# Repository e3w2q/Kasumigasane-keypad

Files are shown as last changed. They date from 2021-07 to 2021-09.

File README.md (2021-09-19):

# Kasumigasane (霞襲)




## What is Kasumigasane?

Kasumigasane is a simple 16-key keypad that can be assembled without diodes.

*Kasumigasane* (霞襲) means "a layer of misty stuff", because it is made of layers of glass exposi substrates.

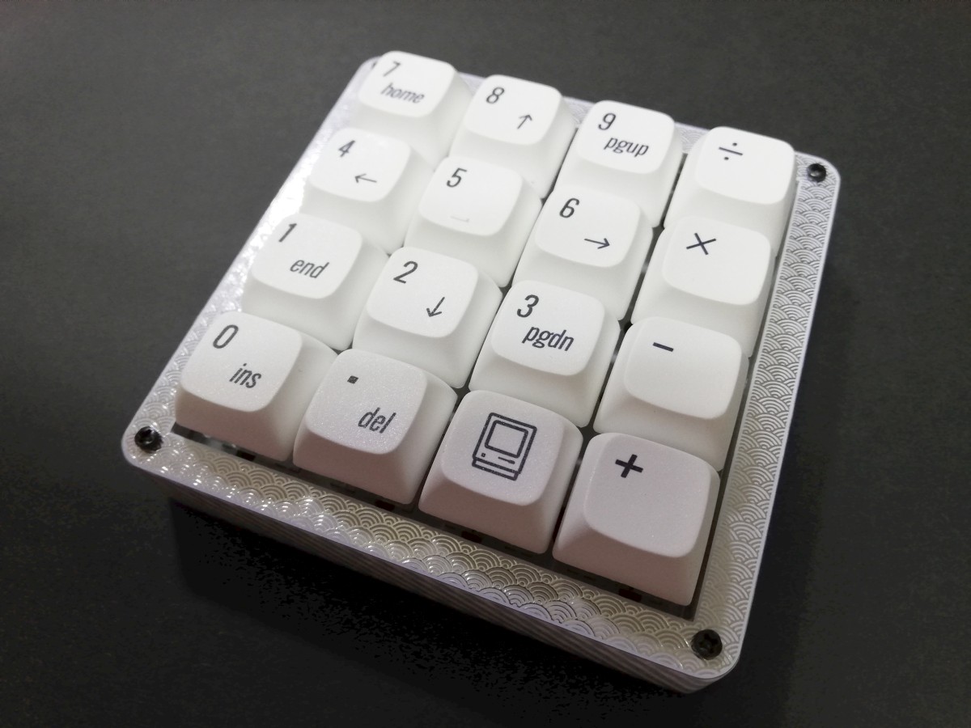
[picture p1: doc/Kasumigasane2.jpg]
Kasumigasane2


## Customizability

You can choose a frame from eight different patterns.

You can decorate the sides with 15mm wide masking tape.

The rightmost column and the lowermost row can use the 2U key.

The upper leftmost key can be replaced by a rotary encoder.

Backlight LED can be soldered.

## Link

[Hardware data (PCB)](pcb/)

[Firmware](https://github.com/e3w2q/qmk_firmware/tree/e3w2q/keyboards/e3w2q/kasumigasane)

[PCBの入手方法](doc/pcb_order_guide_jp.md)

[パーツリスト](doc/bom_list_jp.md)

[ビルドガイド](doc/readme_jp.md)

## Short Story

キーの上に指を走らせる。画面に文字が浮かび上がり、文章が出力されていく。つくづく現代、キータイプという作業と仕事は切り離せない関係になった。私のような文筆業のものにとっては、尚更である。<br />
キーボードは、ハードウェアと人間を繋ぐインターフェースのなかでもかなり原始的な部類のものだ。起源としては一八七三年に登場したタイプライターだが、日本語のワード・プロセッサーが登場したのは比較的最近の一九七九年。それでもおおよそ五〇年間、人間はこのデバイスと付き合ってきたと言っていい。<br />
その中でキーボードは進化を遂げてきた。キーボードは極論、『打った内容を正確にハードウェアに伝える』——ただそのためだけの役割の道具だが、人間の手に最も長い時間触れるデバイスの一つである。<br />
数々の高級キーボードが、進化の中で姿を現した。人間工学に配慮したもの、あるいは打鍵感を追求したもの、外見の高級感を備えたもの——近年では、自分に合うものをこそ自作しよう、という風潮まである。キーボードは簡単な電子回路と物理的接点、即ちスイッチがあれば実装できるデバイスでもある為だ。<br />
キリのいいところまで原稿を進めて、左手を横にスライドさせる。<br />
私は、目を走らせることなく、メインキーボードの横にあるキーを叩いた。——見ずとも打てるほどに慣れた配置。<br />
そう。メインキーボードの横には、四×四のオーソリニア・レイアウトをしたテンキーが鎮座している。これもまた、件の自作キーボードの一つだ。ベースは黒の落ち着いた筐体。好みでキートップはチェッカーフラッグ様の配色としてある。<br />
キー押下一つで、マクロが走り、エディタの校閲機能が起動、文章を精査する。——これも自作キーボードの魅力の一つだ。ユーザーがマクロ機能を作り込むことで、この小さなテンキーは作業効率を大きく変えうるワイルドカードとなる。<br />
あぶり出された誤字と誤用を、テンキー操作でジャンプしながら修正していく。<br />
明日も、明後日も、この小さな相棒は、私の手の左で、辣腕の執事のように活躍の機会を待っていてくれるだろう。<br />
——このテンキーの名前は、霞襲（かすみがさね）。

## Photos

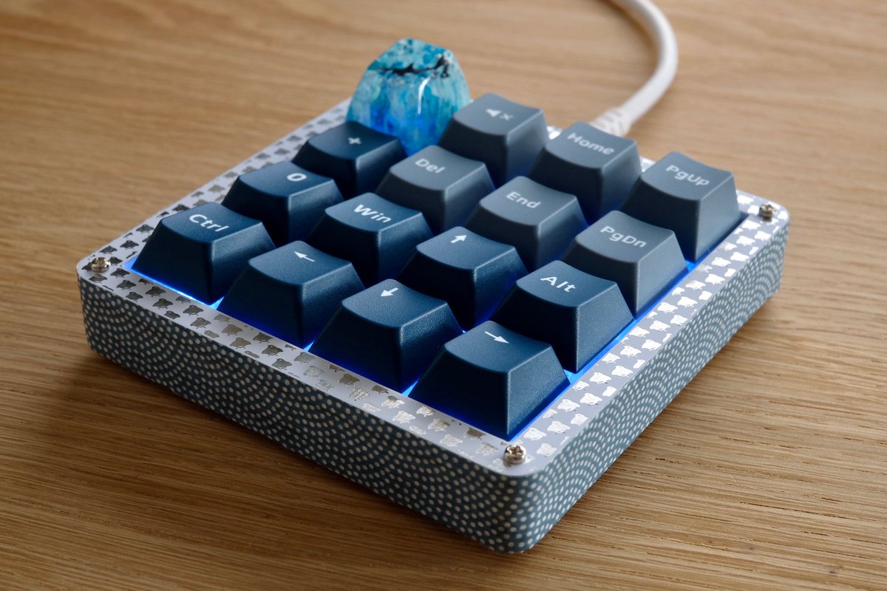
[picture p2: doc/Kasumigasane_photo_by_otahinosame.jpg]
Kasumigasane_photo_by_otahinosame


<small>Photo by @otahinosame</small>

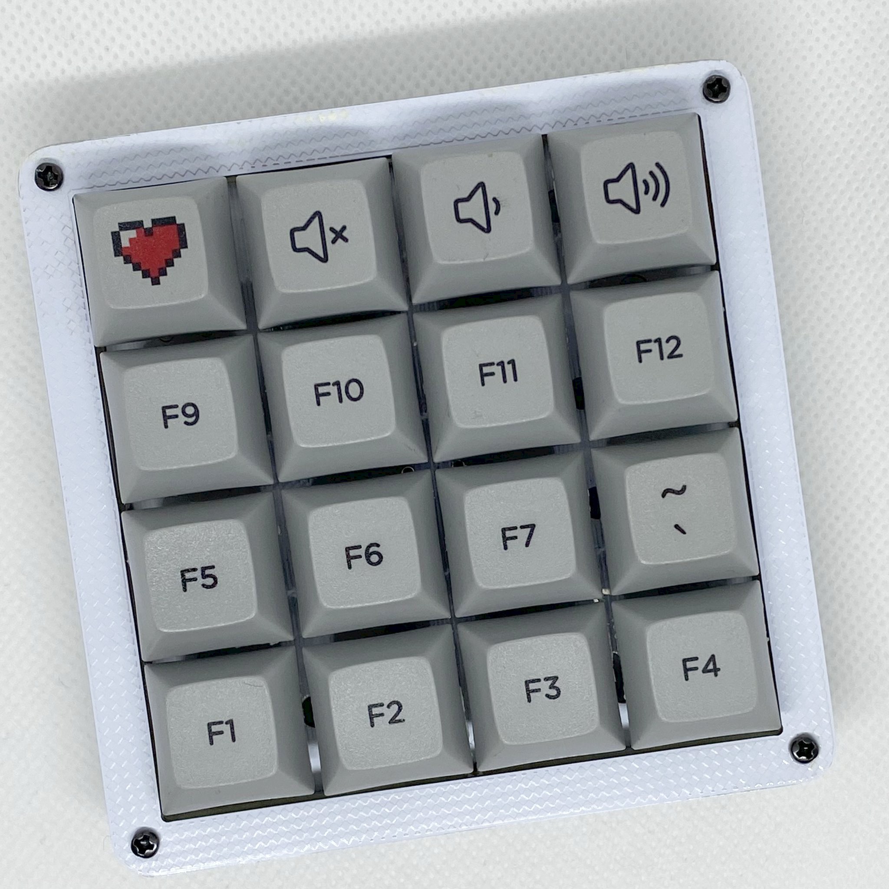
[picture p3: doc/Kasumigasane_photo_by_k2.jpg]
Kasumigasane_photo_by_k2


<small>Photo by @k2\_\_\_\_\_\_\_\_\_\_\_</small>

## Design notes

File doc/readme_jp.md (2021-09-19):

# 霞襲 ビルドガイド

<!-- TOC -->

- [霞襲 ビルドガイド](#霞襲-ビルドガイド)
    - [必要なパーツ](#必要なパーツ)
    - [使用する道具、消耗品](#使用する道具消耗品)
    - [組み方の選択](#組み方の選択)
    - [ビルドガイド](#ビルドガイド)
        - [Pro Microのもげ防止加工](#pro-microのもげ防止加工)
        - [基板のカット](#基板のカット)
        - [基板側面のヤスリがけ](#基板側面のヤスリがけ)
        - [はんだ付けのイメージトレーニング](#はんだ付けのイメージトレーニング)
        - [土台の組み立て](#土台の組み立て)
        - [Pro Microの取り付け](#pro-microの取り付け)
        - [ダイオードの取り付け](#ダイオードの取り付け)
        - [バックライト用LEDの取り付け（バックライトで光らせたい場合のみ）](#バックライト用ledの取り付けバックライトで光らせたい場合のみ)
        - [ロータリーエンコーダの取り付け（ロータリーエンコーダを使いたい場合のみ）](#ロータリーエンコーダの取り付けロータリーエンコーダを使いたい場合のみ)
        - [スタビライザーの取り付け（2Uキーを使いたい場合のみ）](#スタビライザーの取り付け2uキーを使いたい場合のみ)
        - [キースイッチの取り付け](#キースイッチの取り付け)
        - [枠の組み立て](#枠の組み立て)
        - [マスキングテープの貼り付け](#マスキングテープの貼り付け)
        - [Pro Microの再取り付け](#pro-microの再取り付け)
        - [カプトンテープの貼り付け（任意）](#カプトンテープの貼り付け任意)
        - [キーキャップの取り付け](#キーキャップの取り付け)
        - [ゴム足の取り付け](#ゴム足の取り付け)
        - [ファームウェアの書き込み](#ファームウェアの書き込み)
    - [トラブルシューティング](#トラブルシューティング)

<!-- /TOC -->

## 必要なパーツ

[霞襲 パーツリスト](bom_list_jp.md)をご覧ください。

## 使用する道具、消耗品

[使用する道具、消耗品](tool_guide_jp.md)におすすめの道具類、注意事項等をまとめましたのでご覧ください。

## 組み方の選択

右端の1列、一番下の1行は、スタビライザーを付けて2Uキーが取り付けできます。

左上のキーをロータリーエンコーダに置き換えできます。ただし、バックライトとの併用はできません。

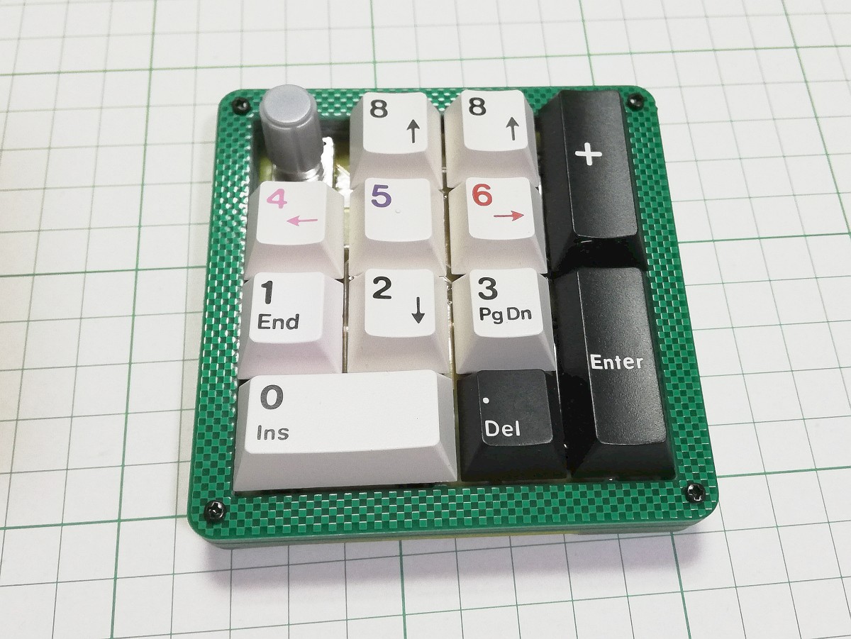
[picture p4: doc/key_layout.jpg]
key_layout


LEDを取り付けて、バックライトで光らせることができます。ただし、ロータリーエンコーダとの併用はできません。

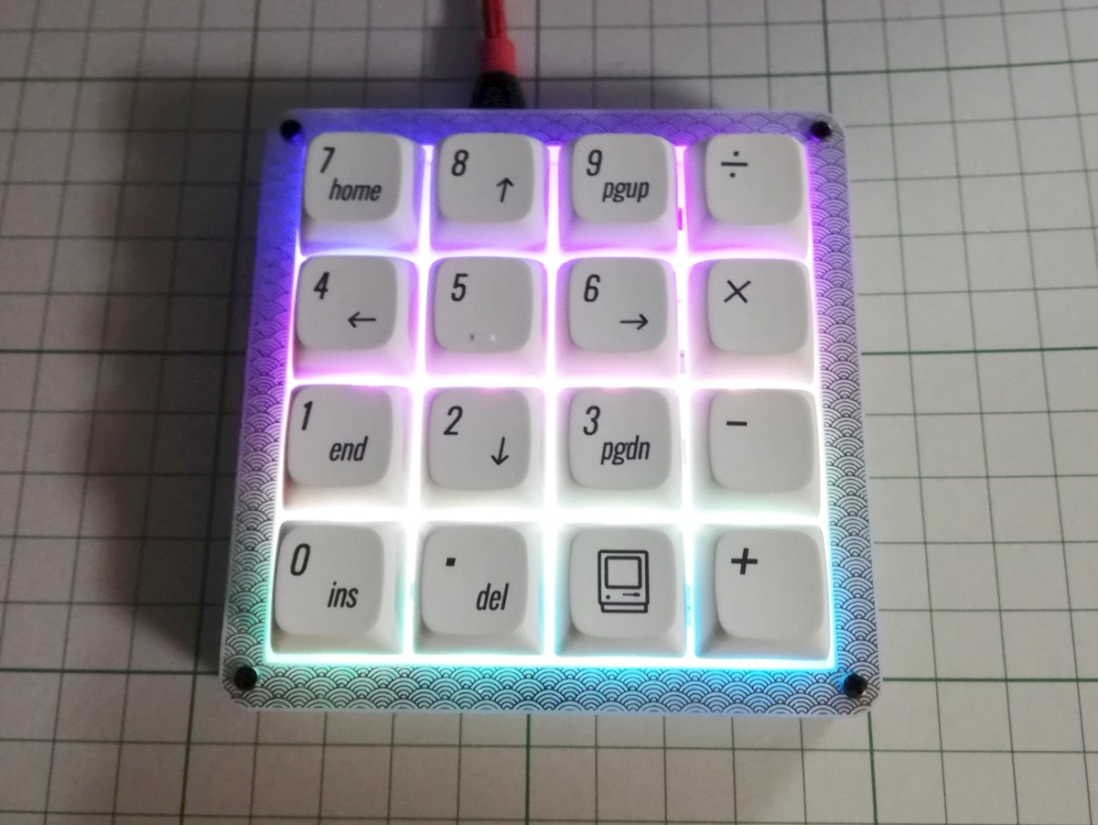
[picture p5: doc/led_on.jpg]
led_on


## ビルドガイド

### Pro Microのもげ防止加工

Pro Microにエポキシ接着剤を盛って、簡単にはもげないようにします。

参考1:[ProMicroのモゲ防止ついでにQMK_Firmwareを書き込む - Qiita](https://qiita.com/hdbx/items/2f3e4ddfcadda2a5578e)
参考2:[もげ予防 - Self-Made Keyboards in Japan](https://scrapbox.io/self-made-kbds-ja/%E3%82%82%E3%81%92%E4%BA%88%E9%98%B2)

エポキシ接着剤の2液を混ぜます。

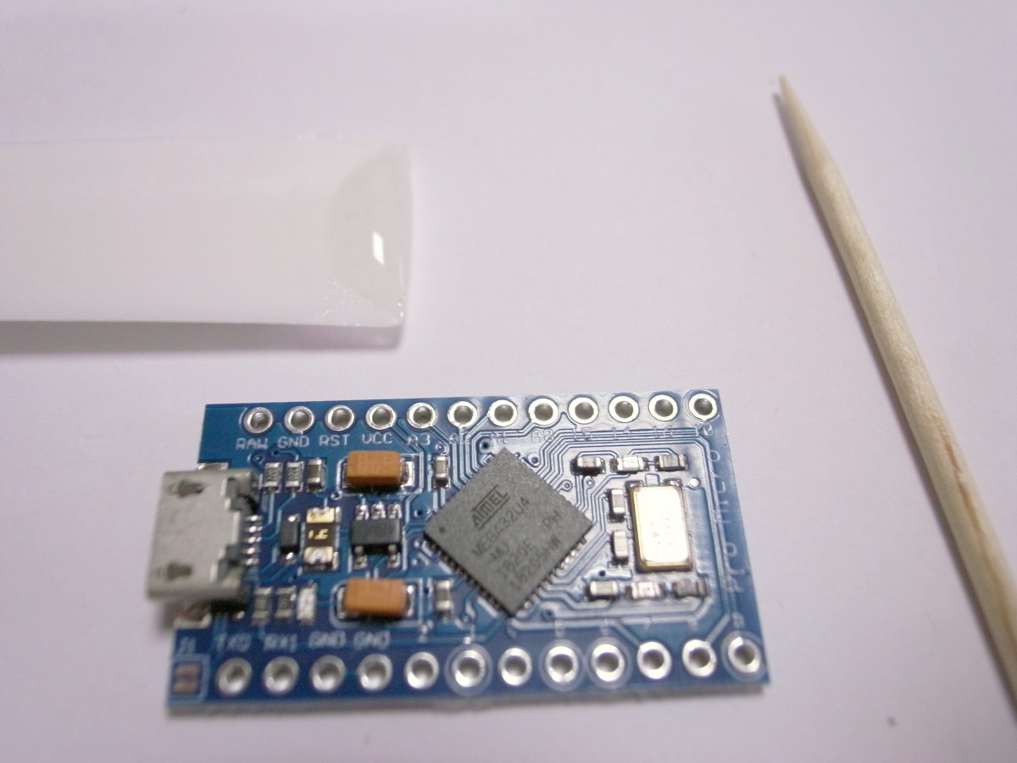
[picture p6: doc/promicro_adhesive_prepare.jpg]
adhesive_prepare


接着剤を付け始める前にMicro USBコネクタを横から見てください。側面に穴が開いています。この穴に接着剤が入ると端子が入らなくなったり、入りにくくなったりします。

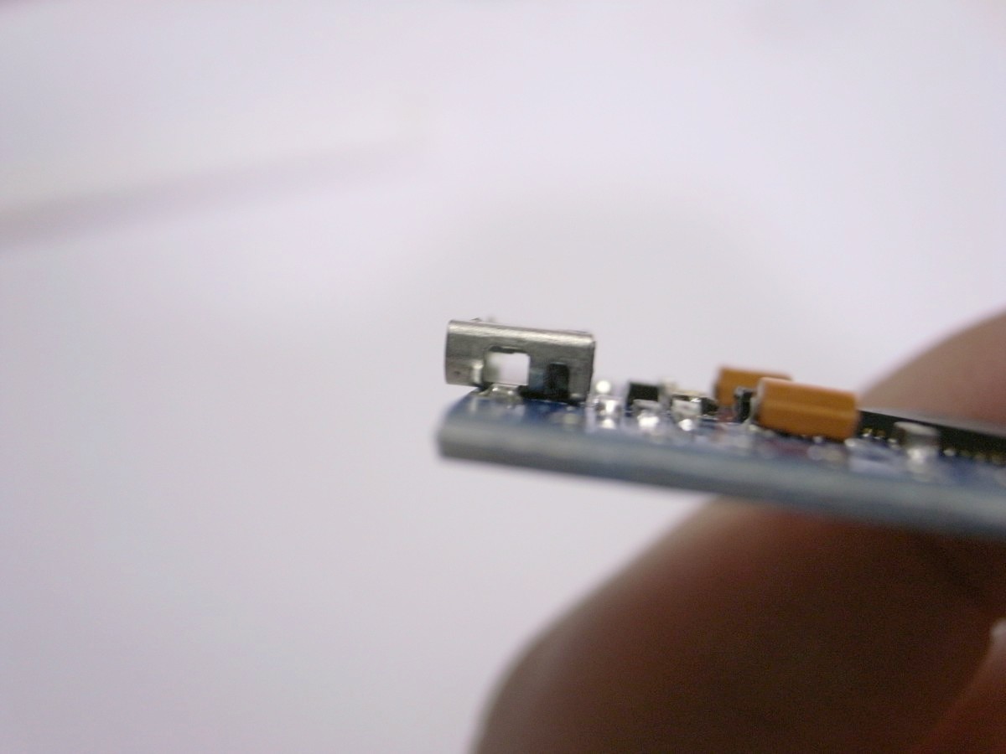
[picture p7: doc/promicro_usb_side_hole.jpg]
usb_side_hole


この穴を避けて、つまようじなどで接着剤を盛っていきます。

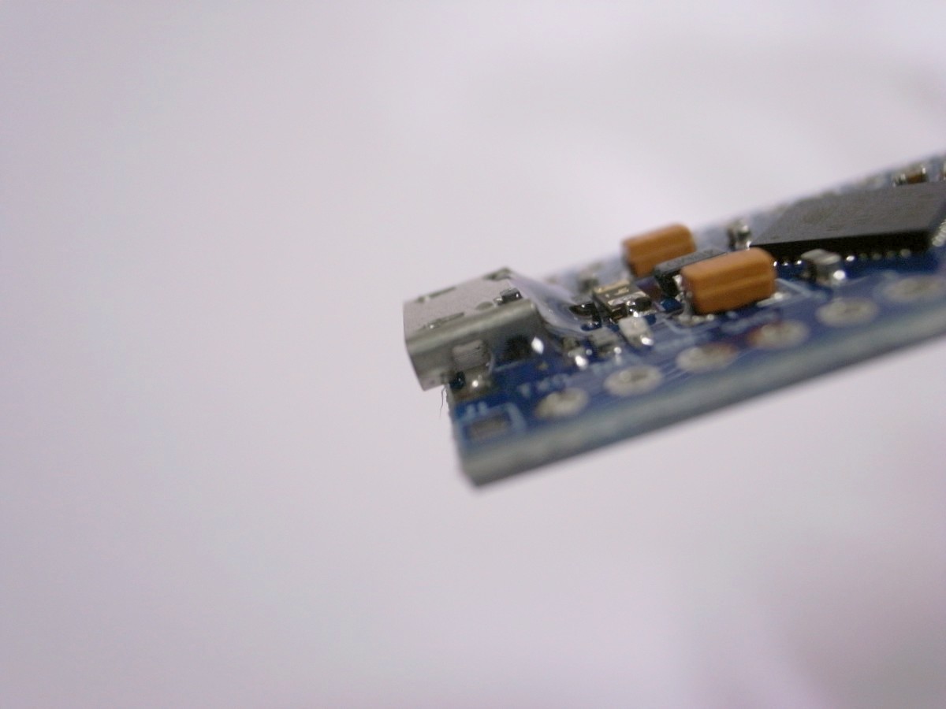
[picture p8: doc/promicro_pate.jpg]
promicro_pate


乾くまで置いておきます。

### 基板のカット

基板の細い部分をニッパーで切断し、各パーツに分けます。パーツや欠片が飛びますので、袋に入れながら行うなど、注意してカットしてください。
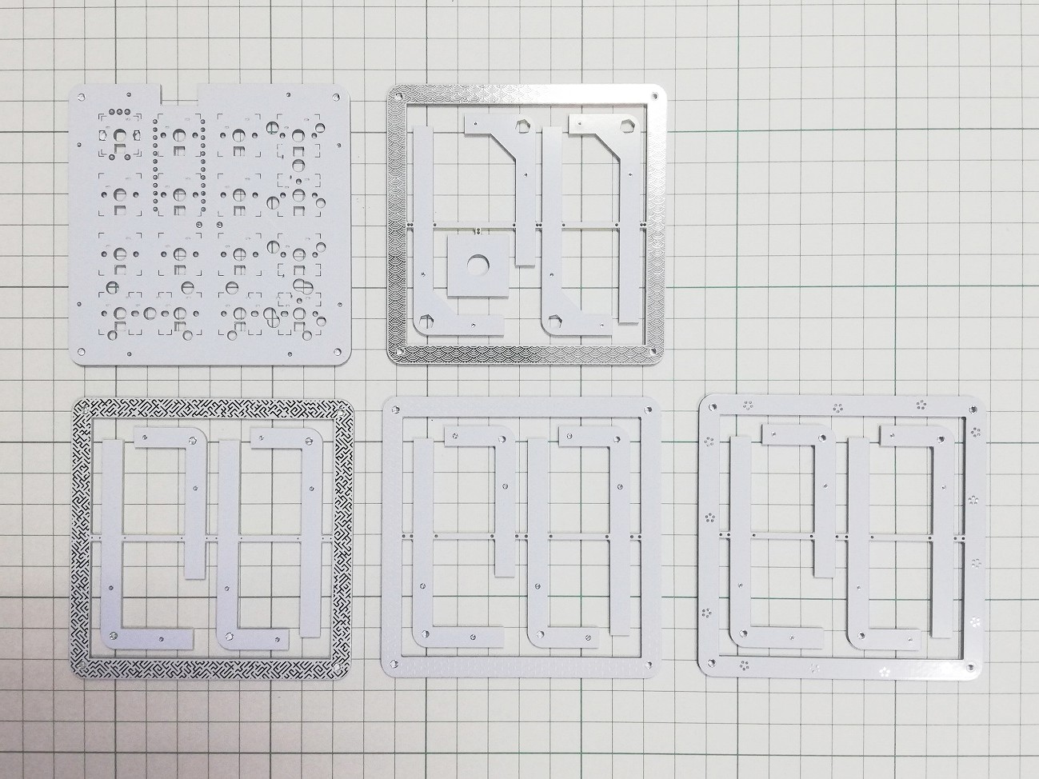
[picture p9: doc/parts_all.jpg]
parts_all


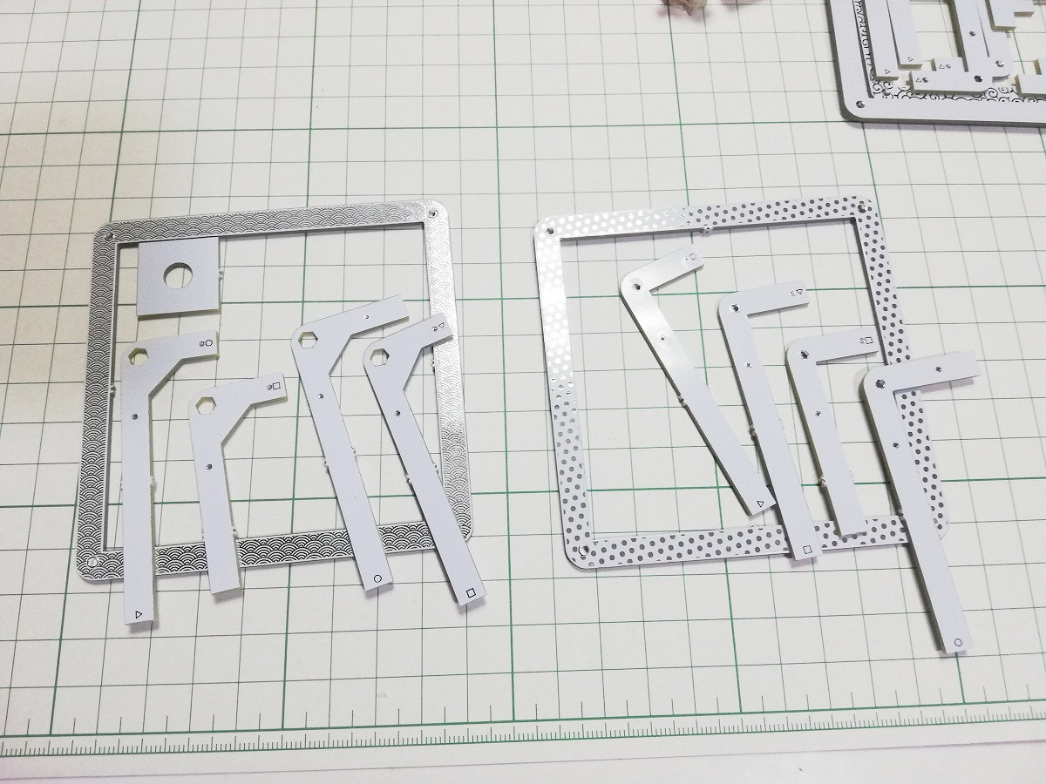
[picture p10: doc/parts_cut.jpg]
parts_cut


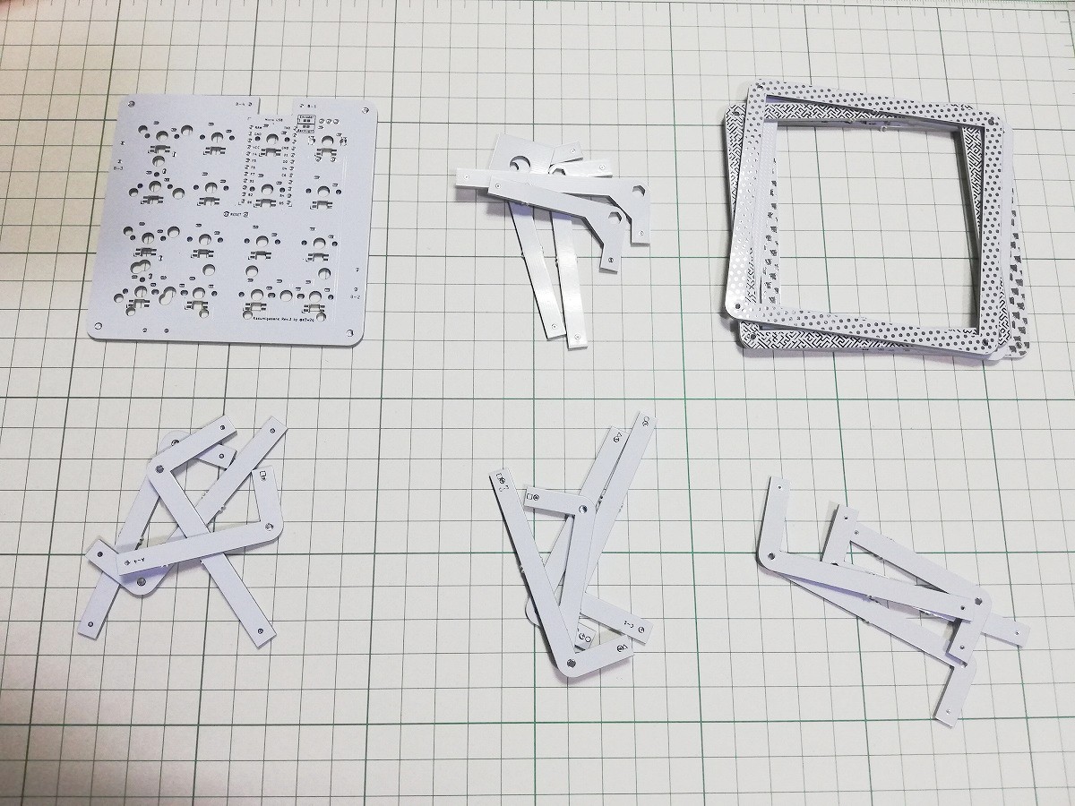
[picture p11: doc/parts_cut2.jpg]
parts_cut2


### 基板側面のヤスリがけ

基板の側面のバリをヤスリで整えます。紙ヤスリの場合、机の角に置き、その上でヤスリがけします。

### はんだ付けのイメージトレーニング

はんだ付けに慣れている方は次の項に進んでください。

全くはんだ付けをしたことがなかったり、数年ぶりにはんだ付けをする場合は、以下の動画が参考になります。

- [はんだ付けの詳細.m2p - YouTube](https://www.youtube.com/watch?v=ZA-ehWjRfYM)

- [基礎からわかる！自キ入門講座 第8回「自作キーボードのつくりかた #2」 - YouTube](https://www.youtube.com/watch?v=LOC53FeU-QM&t=999)

### 土台の組み立て

下の図のとおり重ねたいので、以下の指示に従って**上側から逆向きに**重ねていきます。
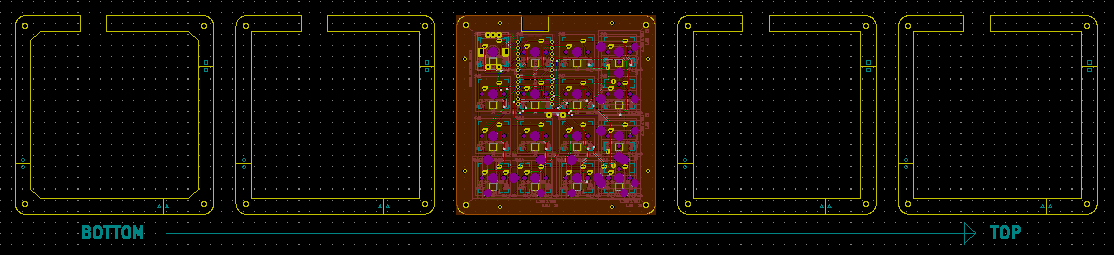
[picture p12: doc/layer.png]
layer


まずはD1～D4を下の写真のとおり並べます。
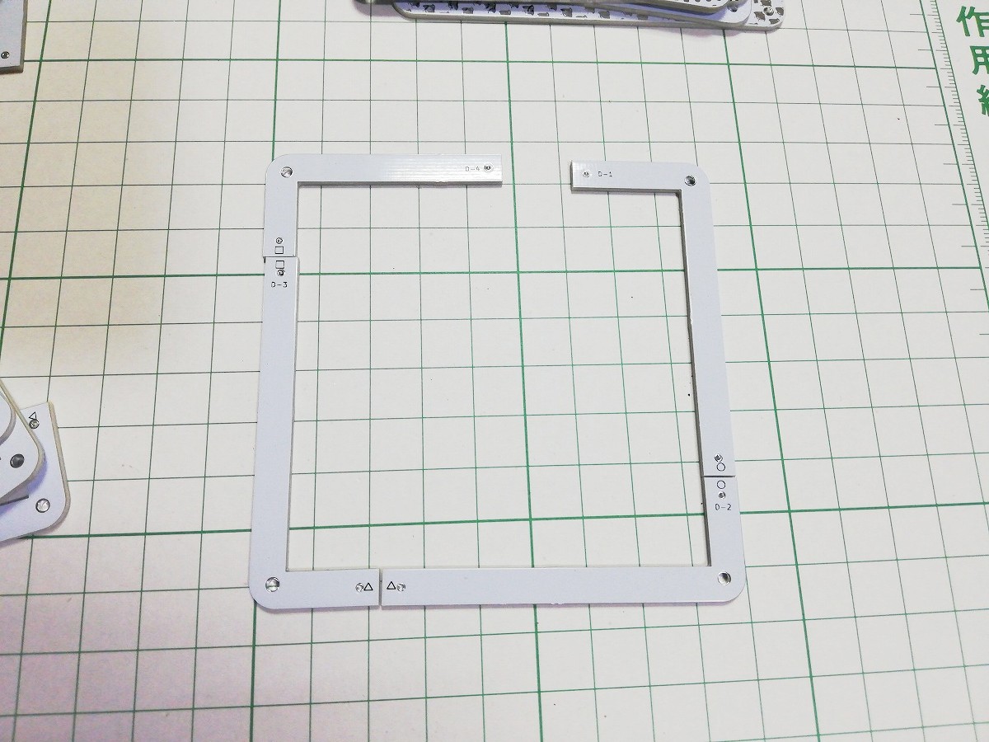
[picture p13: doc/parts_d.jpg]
parts_d


その上にC1～C4を並べます。
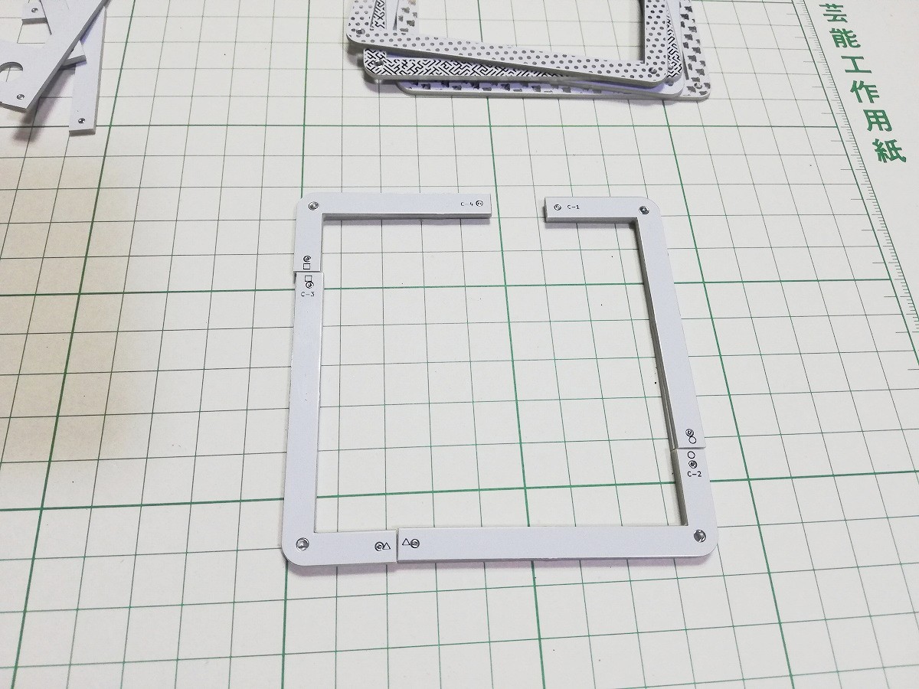
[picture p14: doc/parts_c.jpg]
parts_c


その上に基板を裏向きで置きます。
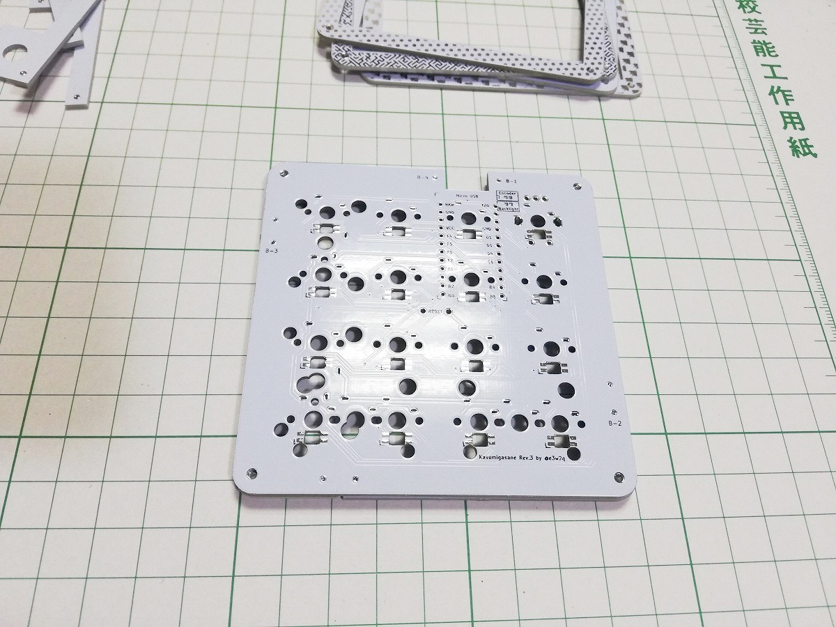
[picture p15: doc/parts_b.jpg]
parts_b


その上にA1～A4を並べます。
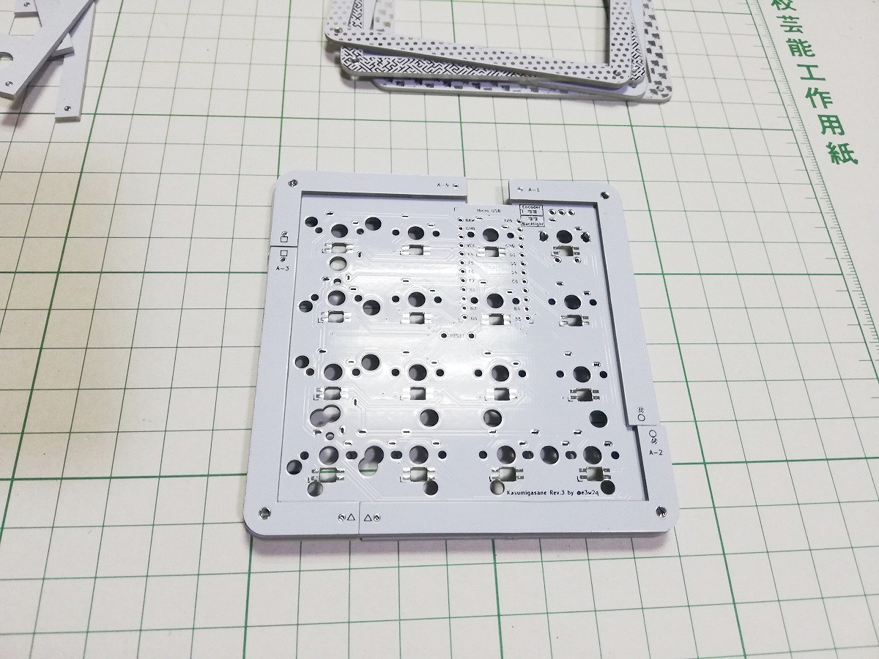
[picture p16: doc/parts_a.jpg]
parts_a


その上に何も書かれていない土台パーツを下の写真のとおり並べます。
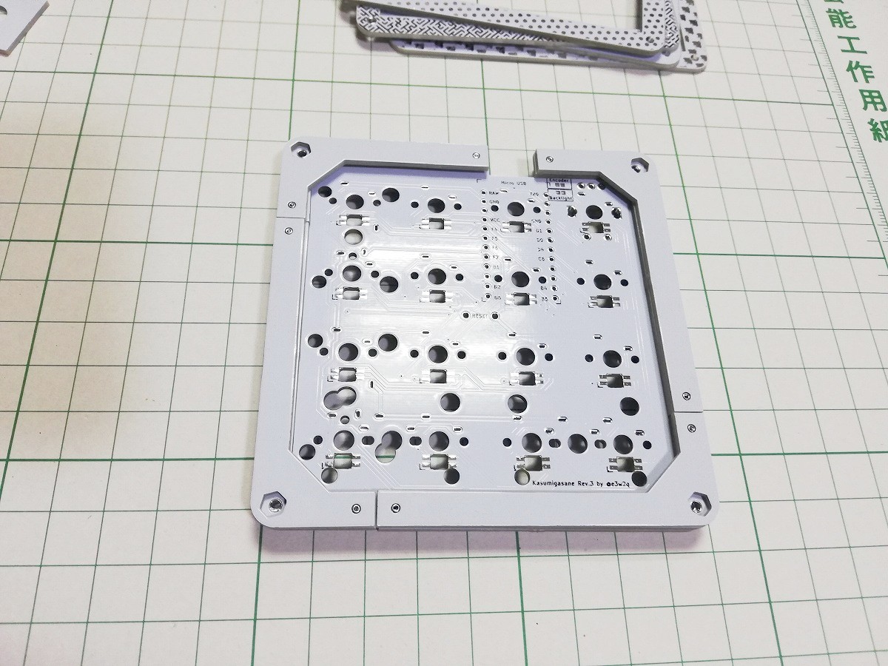
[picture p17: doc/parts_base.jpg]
parts_base


Pro Micro付属のピンヘッダを1本カットし、プラスチック部分を片側にずらします。
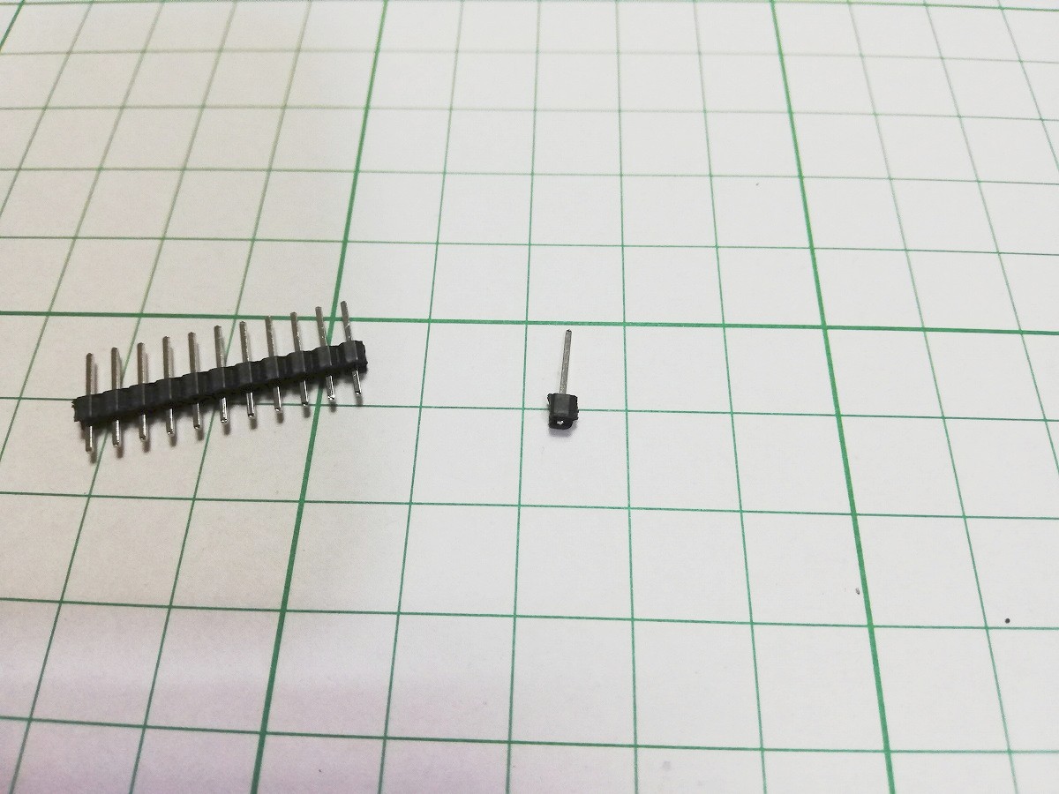
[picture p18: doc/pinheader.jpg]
pinheader


ニッパーで、プラスチック部分のキワでカットします。針金部分を使うので、飛ばないように注意してカットしてください。
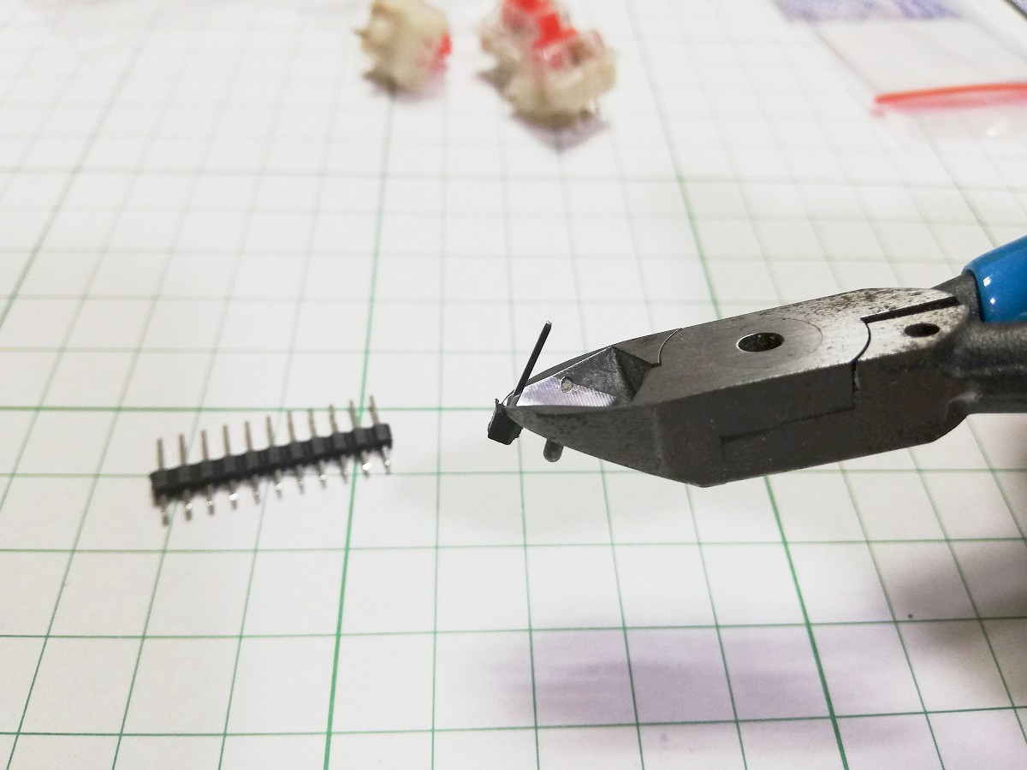
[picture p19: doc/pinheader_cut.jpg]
pinheader_cut


カットしたピンを、先ほど重ねた土台パーツの小さい穴に差し込み、一番下まで通します。
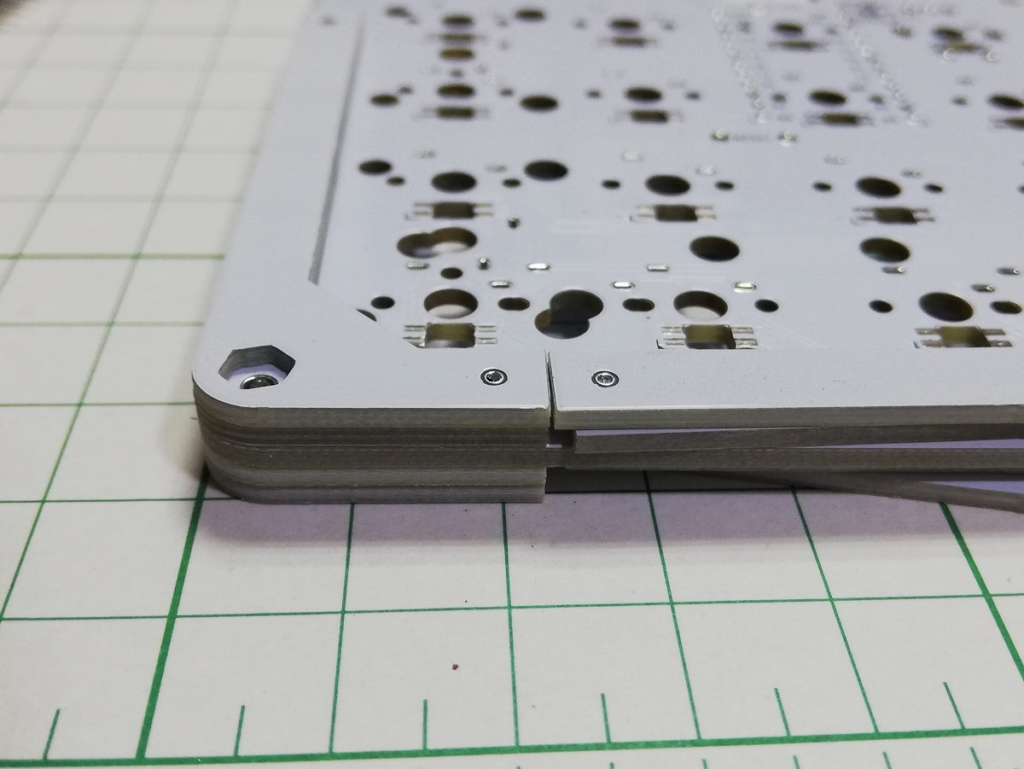
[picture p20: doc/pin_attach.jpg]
pin_attach


裏面からはんだ付けします。基板が浮かないように、押し付けながら行ってください。
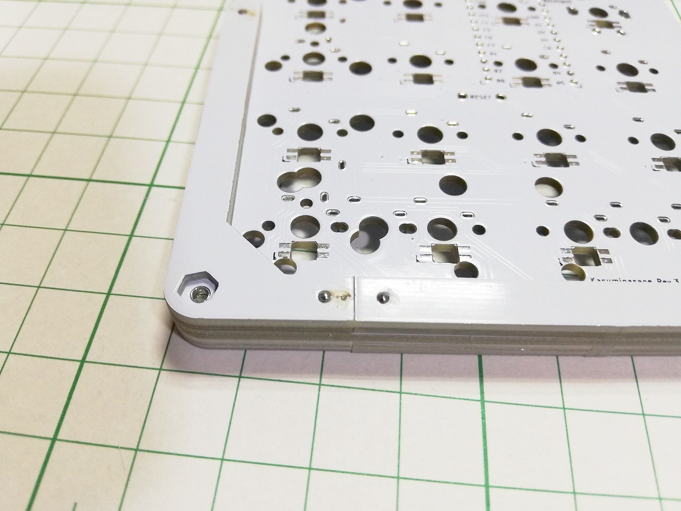
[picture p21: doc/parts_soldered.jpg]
parts_soldered


裏返して表面からはんだ付けします。半田が盛り上がると上から枠パーツを重ねたときに隙間ができてしまうので、盛り上がらない程度に半田を少しだけ流し込んでください。もし半田を入れすぎたら、吸い取り線で吸って減らしてください。
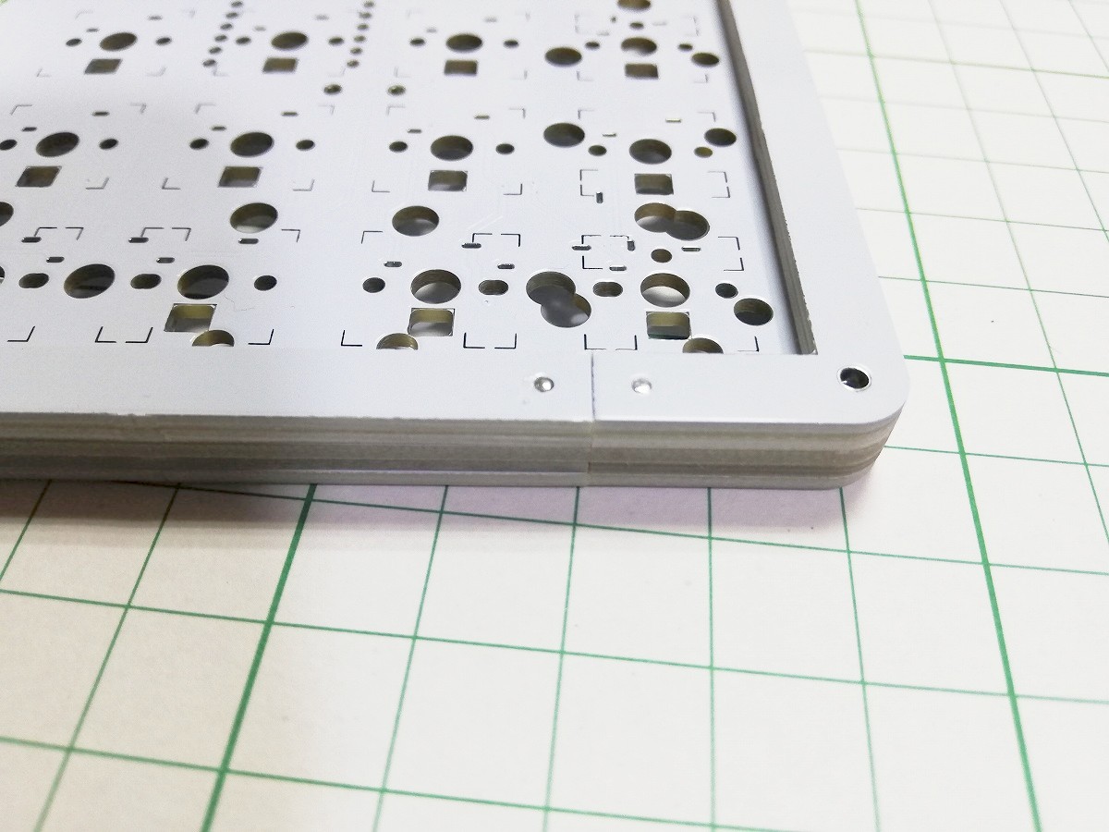
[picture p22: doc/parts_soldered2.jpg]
parts_soldered2


外周の8箇所について同様のことを行うと、土台が完成します。

表側から見た様子

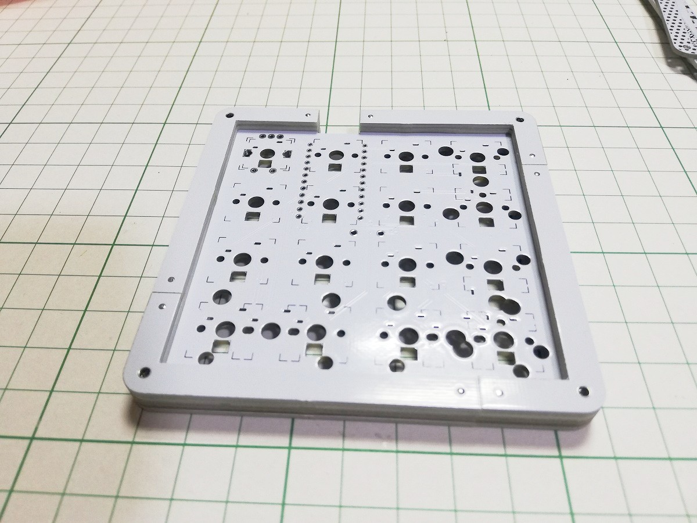
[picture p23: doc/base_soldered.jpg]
base_soldered


裏側から見た様子

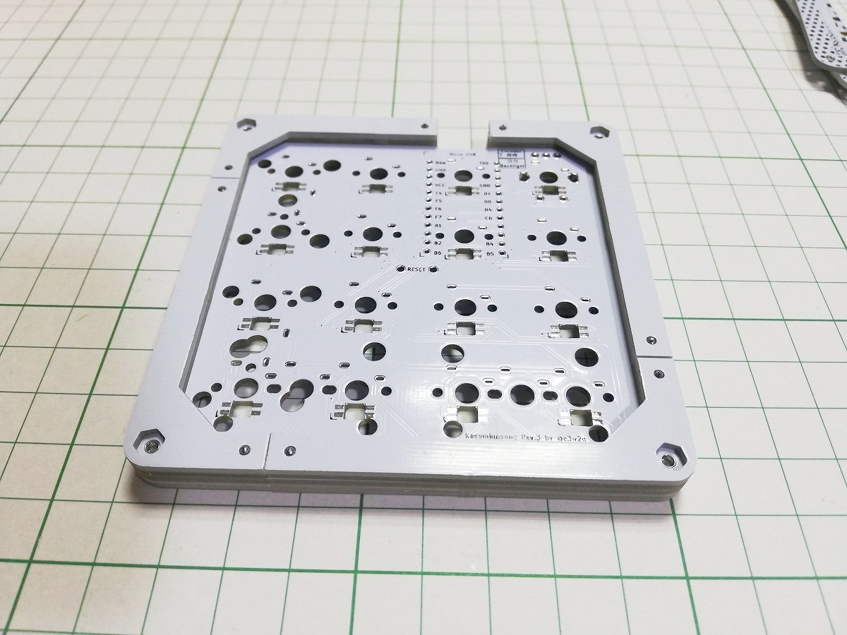
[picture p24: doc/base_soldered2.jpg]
base_soldered2


### Pro Microの取り付け

**基板裏側**のPro Micro設置部分のスルーホールに、コンスルーピンヘッダを根本まで差し込みます。

その際、

- コンスルーピンヘッダの金色の窓が遠い側を基板側とし、金色の窓が近い側をProMicro側とする
- 金色の窓の向きを揃える

ようにしてください。

参考: [Helixベータ ビルドガイド](https://github.com/MakotoKurauchi/helix/blob/master/Doc/buildguide_jp.md#pro-micro)

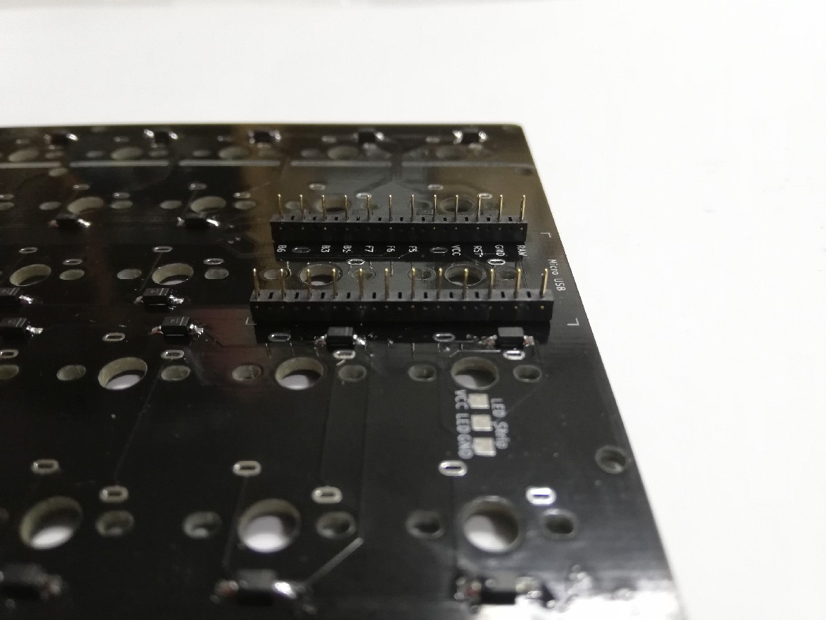
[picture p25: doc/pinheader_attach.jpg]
pinheader_attach


ピンヘッダにPro Microを差し込みます。**Pro Microの裏面（平らなほう）が上になるように、またマイクロUSBが基板端になるように**します。

**向きを間違えるとリカバリーが大変です。表裏、左右をよく確認してください。**
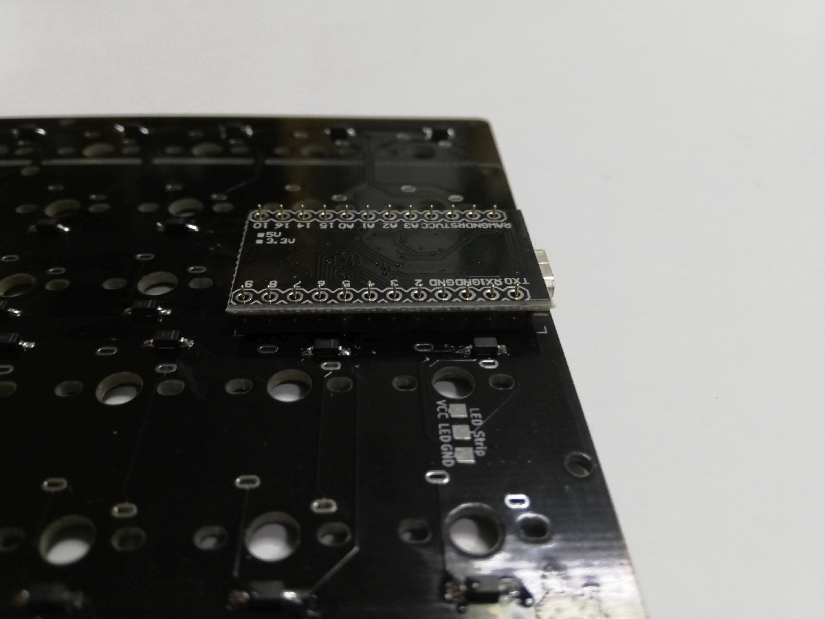
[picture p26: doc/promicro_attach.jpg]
promicro_attach


Pro Microとコンスルーピンヘッダをハンダ付けします。まず四隅をハンダ付けし、横から見てコンスルーピンヘッダとの間に隙間があれば押さえながらハンダを温めて浮かないようにします。そのあと、順番に全てハンダ付けします。
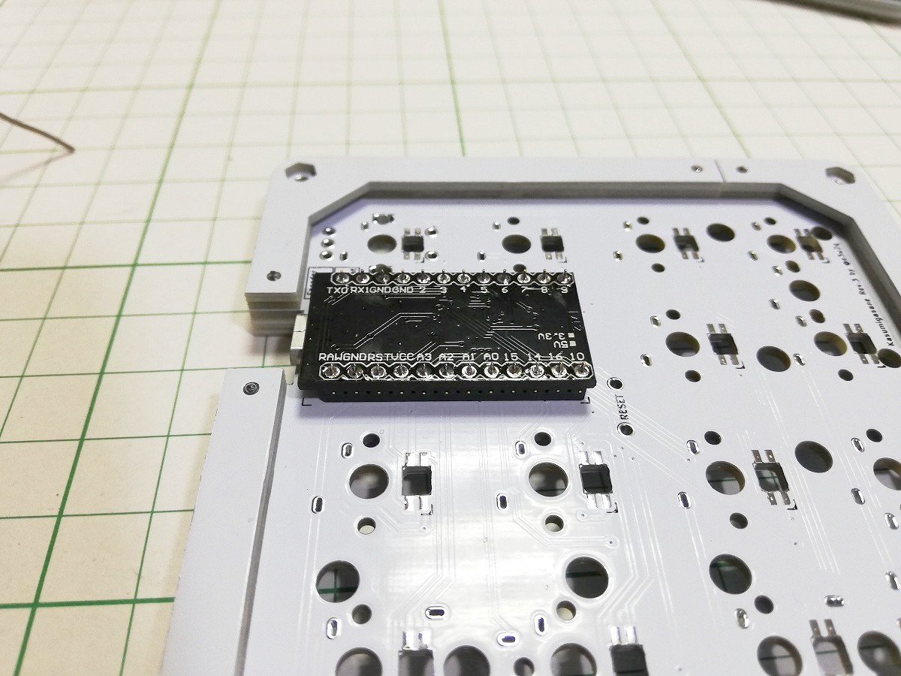
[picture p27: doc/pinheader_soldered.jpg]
pinheader_soldered


基板とコンスルーピンヘッダは接触しているため、ハンダ付けしません。

次に進む前に、一度Pro Microを基板から外します。

Pro Microの各ピンの穴に誤ってハンダが付かないように、マスキングテープでカバーしておくことをおすすめします。

### ダイオードの取り付け

このキーパッドはキーマトリクスを使わず、各キーがGPIOのピンに接続しているため、ダイオードのはんだ付けは不要です。

### バックライト用LEDの取り付け（バックライトで光らせたい場合のみ）

基板を裏返し、各スイッチにタブ付きのRGBLEDをはんだ付けします。基板の裏側から見たときに、LEDは裏側が見えるようにし、LEDのタブの欠けがシルクのL字と一致するように付けます。

led_position

Backlightと書かれたジャンパをハンダで導通させます。

led_jamper

### ロータリーエンコーダの取り付け（ロータリーエンコーダを使いたい場合のみ）

右上のキーの位置にロータリーエンコーダを差し込み、はんだ付けします。一気にはんだ付けせず、まずは対角の2箇所をはんだ付けし、浮きがないことを確認してから残りをはんだ付けしてください。浮きがあれば、はんだを温めながら押すと直せます。

Encoderと書かれたジャンパをハンダで導通させます。

### スタビライザーの取り付け（2Uキーを使いたい場合のみ）

表側からスタビライザーを装着します。基板の穴の大小と、スタビライザーのポッチの大小を合わせてください。ネジ止めするタイプのスタビライザーの場合は、裏側からネジ止めします。

### キースイッチの取り付け

表側から差し込みます。トッププレート無しでもキースイッチのガタつきがないよう、穴のサイズを小さめにしてあります。ギュッと押し込んでください。キースイッチの足が曲がっている場合はまっすぐにしてから差し込んでください。

**Pro Microが取り付けられる部分のスイッチ2個は、差し込む前に端子をカットし、基板からはみ出さないようにしてください**

全部のキースイッチを差し込み終わったら、サイド方向からよく見て、スイッチが傾いていないか確認してください。
switch_attach

裏面もサイド方向からよく見て、キースイッチの固定用のピンの長さがどのキーも同じぐらい出ているか確認してください。
switch_attach2

### 枠の組み立て

お好みの図柄が一番上になるようにして、枠パーツ4枚を表側に重ねます。
frame_stack

表からM2ネジ、裏にM2ナットを入れて固定します。
nut_attach

端面をやすりで磨くと段差が無くなります。

side_surface_treatment

### マスキングテープの貼り付け

外周部分に、幅15mmの好きな柄のマスキングテープを貼り付けます。

外周部分は幅が大きいため、ガンダムマーカーやポスカではきれいに塗りにくいです。あと、塗料の場合、隙間に入り込むので枠を入れ替えするときに拭き取らないといけなかったりします。

側面を見栄えよくするポイント：

- マスキングテープテープでは側面の段差はあまりカバーできないので、もし重ねた基板の段差が気になるようなら、側面をヤスリがけしてください。
- マスキングテープは若干透けます。透けが気になる場合は、まず単色のマスキングテープを貼ってから、その上に好きな柄のマスキングテープを貼ると、ちょっとよくなります。
- マスキングテープの幅15mmに対して、側面の高さが14.4mmなので、ちょっとだけマスキングテープのほうが幅広です。マスキングテープは上面に合わせて貼って、下側のちょっとだけはみ出した部分を底面に折り込むとよいです。

side_maskingtape

### Pro Microの再取り付け

裏からPro Microを再度取り付けます。
promicro_reattach

### カプトンテープの貼り付け（任意）

Pro Microが机に接触することはないように設計していますが、柔らかいデスクマットの上や膝の上や金属のテーブルの上で使用する場合は、Pro Microのピンの上にカプトンテープを貼ることをおすすめします。
captontape_attach

### キーキャップの取り付け

キースイッチにキーキャップをはめます。
keycap_attach

### ゴム足の取り付け

ゴム足を半分にカットして、裏面の四隅に取り付けます。

rubberfoot_attach

### ファームウェアの書き込み

[霞襲 ファームウェアの書き込み](firmware_jp.md)をご覧ください。

## トラブルシューティング

- 特定のキーが反応しない
  
  - キースイッチのハンダ付けが甘い場合があります。キースイッチを押すかわりに、キースイッチの裏面のハンダ2箇所をピンセットでショートさせてみて、入力されるか確認してください。入力される場合は、ハンダ付けし直してみてください。
- バックライトLEDが点灯しない
  
  - 以下のページが参考になります。
  
    [[自作キーボード]LEDがつかない/光らないときに見るページ - Qiita](https://qiita.com/tez/items/03c2daec5d3aed8dd558)

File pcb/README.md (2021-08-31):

# Kasumigasane PCB Data

## Schematic
Schematic

## PCB Layout
PCB Layout

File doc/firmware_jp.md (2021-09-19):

# 霞襲 ファームウェアの書き込み

ここでは、ファームウェアを書き込む3種類の方法を記載します。

[Pro Micro Web UpdaterとRemapを使う場合](#pro-micro-web-updaterとremapを使う場合)が手軽でおすすめです。

より詳しく設定したい場合は、[QMK Firmwareのコマンドを使う場合](#qmk-firmwareのコマンドを使う場合)を参照してください。

<!-- TOC -->

- [霞襲 ファームウェアの書き込み](#霞襲-ファームウェアの書き込み)
    - [Pro Micro Web UpdaterとRemapを使う場合](#pro-micro-web-updaterとremapを使う場合)
        - [ファームウェアのダウンロード](#ファームウェアのダウンロード)
        - [Pro Micro Web Updaterを使ったファームウェアの書き込み](#pro-micro-web-updaterを使ったファームウェアの書き込み)
        - [Remapでのキー書き換え](#remapでのキー書き換え)
    - [QMK ToolboxとVIAを使う場合](#qmk-toolboxとviaを使う場合)
        - [ファームウェア・キーマップJSONのダウンロード](#ファームウェア・キーマップjsonのダウンロード)
        - [QMK Toolboxのインストール](#qmk-toolboxのインストール)
        - [QMK Toolboxを使ったファームウェアの書き込み](#qmk-toolboxを使ったファームウェアの書き込み)
        - [VIAのインストール](#viaのインストール)
        - [VIAでのキー書き換え](#viaでのキー書き換え)
    - [QMK Firmwareのコマンドを使う場合](#qmk-firmwareのコマンドを使う場合)

<!-- /TOC -->

## Pro Micro Web UpdaterとRemapを使う場合

### ファームウェアのダウンロード

以下のzipファイルをダウンロードして保存してください。Remapでは使いませんが、キーマップJSONも同梱してあります。

- https://github.com/e3w2q/Kasumigasane-keypad/blob/main/firmware/e3w2q_kasumigasane_via.zip?raw=true

zipファイルの中のhexファイルを取り出してください。

### Pro Micro Web Updaterを使ったファームウェアの書き込み

- [Pro Micro Web Updater](https://sekigon-gonnoc.github.io/promicro-web-updater/index.html)

霞襲をPCに接続した状態で、Pro Micro Web Updaterにアクセスし、先ほど取り出したhexファイルを選択し、「flash」をクリックします。

シリアルポートへの接続要求の画面が出ます。

霞襲の裏面中央のRESETと書かれたところの左右の穴をピンセットやクリップなどで短絡させ、出てきたUSBシリアルデバイスを選択して「接続」をクリックします。

するとファームウェアが書き込まれます。

### Remapでのキー書き換え

- [Remap](https://remap-keys.app/)

霞襲をPCに接続した状態で、RemapのWebサイトにアクセスし、「START REMAP FOR YOUR KEYBOARD」をクリックします。

「+KEYBOARD」をクリックします。

HIDデバイスへの接続要求の画面が出ます。

「Kasumigasane」を選択して「接続」をクリックします。

キー割り当てを変更できる画面が表示されます。

キー割り当てを変更して右上の「flash」をクリックすると、変更されます。

## QMK ToolboxとVIAを使う場合

### ファームウェア・キーマップJSONのダウンロード

以下のzipファイルをダウンロードして保存してください。

- https://github.com/e3w2q/Kasumigasane-keypad/blob/main/firmware/e3w2q_kasumigasane_via.zip?raw=true

zipファイルの中のhexファイルとjsonファイルを取り出してください。

### QMK Toolboxのインストール

- [Releases ・ qmk/qmk_toolbox ・ GitHub](https://github.com/qmk/qmk_toolbox/releases)

からダウンロードし、実行します。Windowsの場合、「qmk_toolbox.exe」です。

Windowsでは最初の実行時に必要なドライバーをインストールするように求められます。

### QMK Toolboxを使ったファームウェアの書き込み

サリチル酸さんの解説ページがわかりやすいです。

- [（初心者編）自作キーボードにファームウェアを書き込む - 自作キーボード温泉街の歩き方](https://salicylic-acid3.hatenablog.com/entry/qmk-toolbox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)

霞襲をPCに接続した状態で、QMK Toolboxの右上の「Open」をクリックし、先ほど取り出したhexファイルを選択し、「Flash」をクリックします。

霞襲の裏面中央のRESETと書かれたところの左右の穴をピンセットやクリップなどで短絡させると書き込みが始まります。

### VIAのインストール

- [Releases ・ the-via/releases ・ GitHub](https://github.com/the-via/releases/releases/tag/v1.3.1)

からダウンロードし、実行します。Windowsの場合、「via-*-win.exe」です。

### VIAでのキー書き換え

サリチル酸さんの解説ページがわかりやすいです。

- [（初心者編）VIAを使ってキーマップを書き換えよう - 自作キーボード温泉街の歩き方](https://salicylic-acid3.hatenablog.com/entry/via-manual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)

VIAを起動したあと、左上の「File」→「Import Keymap」をクリックし、先ほど取り出したjsonファイルを選択します。

キー割り当てを変更できる画面が表示されます。

VIAの画面でキー割り当てを変更するとその都度キーボード側にも設定が反映されます。

## QMK Firmwareのコマンドを使う場合

以下のリンク先を参考にして、QMK Firmwareのビルド環境を用意します。

- Windows
  - [QMKビルド環境の構築(Windows Msys2編)](https://gist.github.com/e3w2q/4bc86e531d1c893d3d13af3e9895a94a)
- macOS
  - [セットアップ - QMK Firmware](https://docs.qmk.fm/#/ja/newbs_getting_started?id=macos)
- Linux
  - [セットアップ - QMK Firmware](https://docs.qmk.fm/#/ja/newbs_getting_started?id=linux)

構築中、

```
qmk setup
```

と入力する代わりに

```
qmk setup e3w2q/qmk_firmware --branch e3w2q
```

と入力してください。

または、`qmk setup`した後に、`C:\Users\USER_NAME\qmk_firmware\keyboards`配下に[https://github.com/e3w2q/qmk_firmware/tree/e3w2q/keyboards/e3w2q](https://github.com/e3w2q/qmk_firmware/tree/e3w2q/keyboards/e3w2q)以下をコピーしてもよいです。

用意されたキーマップを書き込むには以下を実行します。

```
qmk flash -kb e3w2q/kasumigasane -km default
```

`Detecting USB port, reset your controller now...`と表示されたら裏面中央のRESETと書かれたところの左右の穴をピンセットやクリップなどで短絡させると書き込みが始まります。

[QMK Configuratorのテストモード](https://config.qmk.fm/#/test)でキー入力が行えるかテストしてください。

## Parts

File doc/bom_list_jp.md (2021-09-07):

# 霞襲 パーツリスト

| 名前 | 数 | 備考 | 調達先の例 | 参考価格 |
| --- | --- | --- | --- | --- |
| 霞襲 基板 | 1枚 | | [Elecrow Online store](https://www.elecrow.com/) | |
| Pro Micro | 1個 | | https://talpkeyboard.stores.jp/items/5b24504ba6e6ee7ec60063e3 | 550円 |
| 12ピンコンスルー（スプリングピンヘッダ） | 2個 | | https://talpkeyboard.net/items/5e056626d790db16e2889233 | 1個220円 |
| 5ピン仕様のMX互換スイッチ  | 16個 | | https://talpkeyboard.stores.jp/?category_id=59cf8860ed05e668db003f5d | 10個で450円～  |
| キーキャップ | 16個 | 2Uキーを使いたい場合は2Uキー用のものも | https://talpkeyboard.net/?category_id=5e7017ee2a9a421f866eac4b | 2個で110円など |
| クッションゴム | 2個 | | ダイソー クッションゴム 14個入り | 110円 |
| 15～16mm長M2ネジ | 4本 | | https://www.monotaro.com/p/2902/1528/ | 34個で329円 |
| M2ナット | 4個 | | https://www.monotaro.com/p/6105/4693/ | 50個で516円 |
| Micro USBケーブル | 1本 | 通信ができるもの | | |
| 幅15mmのマスキングテープ | 1個以上 | 好きな柄のもの |  |  |

## オプション

| 名前 | 数 | 備考 | 調達先の例 | 参考価格 |
| --- | --- | --- | --- | --- |
| 2U PCBマウントスタビライザー | 1～3個 | 2Uキーを使いたい場合 | https://talpkeyboard.net/?category_id=5f884b9b3313d216eb50558a | 1個600円など |
| ロータリーエンコーダ | 1個 | ロータリーエンコーダを実装する場合<br />バックライトとの併用は不可 | https://talpkeyboard.net/items/5f3f1a597df28129f2fd4b0f | 200円 |
| SK6812MINI-E | 16個 | バックライトを実装する場合<br />ロータリーエンコーダとの併用は不可 | https://akizukidenshi.com/catalog/g/gI-15478/ | 5個で110円 |
| カプトンテープ | 40mm長程度×2 | 柔らかいデスクマットの上や膝の上や金属のテーブルの上で使用する場合 | https://akizukidenshi.com/catalog/g/gT-09379/ | 250円 |

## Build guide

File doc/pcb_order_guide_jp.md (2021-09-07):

# PCBなどの入手方法

## 基板・ボトムプレート

### ELECROWへ発注する場合

[ELECROW基板製造サービス](https://www.elecrow.com/pcb-manufacturing.html)から注文します。

アップロードするガーバーファイルは以下のものを使ってください。

| 概要 | URL | 寸法 |
| ---- | --- | --- |
| 基板 | https://github.com/e3w2q/Kasumigasane-keypad/blob/main/gerber/kasumigasane-pcb-gerber.zip?raw=true | 90×90mm |
| プレート1 | https://github.com/e3w2q/Kasumigasane-keypad/blob/main/gerber/kasumigasane-plate1-gerber-lead-free.zip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 | 90×90mm |
| プレート2 | https://github.com/e3w2q/Kasumigasane-keypad/blob/main/gerber/kasumigasane-plate2-gerber.zip?raw=true | 90×90mm |
| プレート3 | https://github.com/e3w2q/Kasumigasane-keypad/blob/main/gerber/kasumigasane-plate3-gerber.zip?raw=true | 90×90mm |
| プレート4 | https://github.com/e3w2q/Kasumigasane-keypad/blob/main/gerber/kasumigasane-plate4-gerber-lead-free.zip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 | 90×90mm |

PCB Colorはお好みの色を選択してください。

Surface Finishは、プレート1とプレート4はHASL Lead Free（無鉛はんだ）とすることをおすすめします。手に触れうる部分にメッキが露出しているためです。

プレート2とプレート3はメッキの露出はないので、HASLで構いません。

模様を金色にしたい場合はImmersion goldを選択してください。

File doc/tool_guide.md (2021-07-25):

[English](tool_guide.md) / [日本語](tool_guide_jp.md)

# Tools and consumables

## Examples of procured products

This is a list of items that should be procured. The commentary is summarized below.

| Tools, consumables | Product examples | Examples of suppliers | Reference prices |
| ---- | ---- |  ---- |  ---- |
| Soldering iron | White light dial type temperature control soldering iron FX600 | https://www.amazon.co.jp/dp/B006MQD7M4 | 3,900 yen |
| Replacement iron tip | White light tip 2C type T18-C2 | https://www.amazon.co.jp/dp/B004OR7UBM | 478 yen |
| Soldering iron stand | HAKOKO iron stand 633-01 | https://www.amazon.co.jp/dp/B000TGNWCS | 1,680 yen |
| Solder blotter | Sanhayato Solder Shutaro NEO 45W type HSK-300 | https://www.amazon.co.jp/dp/B01FEV2BPG | 4,918 yen |
| Nippers | Engineer Micro Nipper NS-04 | https://www.amazon.co.jp/dp/B000TGJSWG | 1,414 yen |
| Precision screwdriver +0 | Engineer + Precision screwdriver set 6 DM-20 | https://www.amazon.co.jp/dp/B06XXXVPRY | 807 yen |
| Tester | OHM (Ohm Electric) Digital Multi Tester TDB-401 (04-1891) | https://www.amazon.co.jp/dp/B001TVKWWU | 2,543 yen |
| Solder | goot precision printed circuit board solder SD-62 | https://www.amazon.co.jp/dp/B0029LGAMA | 255 yen |
| Equiposhi adhesive two-component mixed type | Cemedine 5 minutes curing epoxy adhesive High Super 5 P15g set CA-188 | https://www.amazon.co.jp/dp/B0036WHO0S | 566 yen |
| Masking tape | Masking tape for 3M Scotch painting 18mm × 18m M40J-18 | https://www.amazon.co.jp/dp/B005JWNJZM | 95 yen |
| Sandpaper | KAKURI Paper File MIX Set, 12 Sheets | https://www.amazon.co.jp/dp/B01ARIEU0A | 436 yen |
| Total | | | 17,092 yen |

## Explanation

### Soldering iron

I do not recommend soldering irons from 100 yen shops.

From [WEBはんだ付け講座 はじめに・・](https://noseseiki.com/kisokouza/01.html)

> Currently, in Japan, soldering irons with no temperature control function are used by the majority of people who solder. These soldering irons have a too high tip temperature of 450-550 ° C. For this reason, most products soldered with this soldering iron will be overheated.

If you don't have much soldering experience or have done it a long time ago, we strongly recommend that you prepare one with temperature control.

### Replacement tip

Since the conical shape attached to the soldering iron from the beginning hits the target and the point, it is difficult for heat to be transmitted, and solder may be placed due to insufficient heating, so replace it with the 2C tip and heat on the surface It is easy to do it if you can.

### Soldering iron stand

Necessary for safely placing the soldering iron.

### Solder blotter or wire

It is good to have it because it is not necessary when soldering fails.

### Nipper

It is used for cutting board / biscuits, cutting diode legs / pin headers.

Nippers are not recommended for 100 yen shops for the following reasons.

- Sharpness is not so good, and it is difficult to cut the diode feet and pin header.
- Since the blade is not a sword, it cannot be cut

### Tester

Necessary for problem isolation when keys cannot be entered.

All you need is a conduction mode.

### Electronic work solder

Leaded type is easy to work with.

Since there are no particularly small parts used for SU120, even a 1mm one can work well, but 0.8mm seems to melt the solder easily.

### Epoxy adhesive two-component mixed type

Used for Pro Micro baldness prevention processing.

### Masking tape

It is used to fix parts when turning the board over by soldering.

## Web page for reference (Japanese)

- [Helix キーボードキットの製作に必要な工具メモ - GitHub](https://gist.github.com/mtei/6957107a676ddfa85bde0ae41f8fa849)
- [自作キーボードを作るために必要なもの - 自作キーボード温泉街の歩き方](https://salicylic-acid3.hatenablog.com/entry/2018/11/24/自作キーボードを作るために必要なもの)
- [自作キーボードの組み立てに使っている工具 | yfuku docs](https://yfuku.com/blog/keyboard/keybord_build_tool/)
- [elephant42 の組み立てかた#工具の準備 · illness072/elephant42](https://github.com/illness072/elephant42/blob/master/docs/build-guide.md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)
- [基礎からわかる！自キ入門講座 第8回「自作キーボードのつくりかた #2」 - YouTube](https://salicylic-acid3.hatenablog.com/entry/2018/11/24/自作キーボードを作るために必要なもの)

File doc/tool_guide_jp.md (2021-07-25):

[English](tool_guide.md) / [日本語](tool_guide_jp.md)

# 使用する道具、消耗品

## 調達製品例

調達するとよいものの一覧です。解説は下にまとめて記載します。

### 松コース（定番と思われる製品）

| 道具、消耗品 | 製品例 | 調達先の例 | 参考価格 |
| --- | --- | --- | --- |
| はんだこて | 白光 ダイヤル式温度制御はんだこて FX600 | https://www.amazon.co.jp/dp/B006MQD7M4 | 3,900円  |
| 交換用こて先 | 白光 こて先 2C型 T18-C2 | https://www.amazon.co.jp/dp/B004OR7UBM | 478円 |
| はんだこて台 | 白光(HAKKO) こて台 633-01 | https://www.amazon.co.jp/dp/B000TGNWCS | 1,680円  |
| はんだ吸取器 | サンハヤト はんだシュッ太郎NEO 45Wタイプ HSK-300 | https://www.amazon.co.jp/dp/B01FEV2BPG | 4,918円  |
| ニッパー | エンジニア マイクロニッパー NS-04 | https://www.amazon.co.jp/dp/B000TGJSWG | 1,414円  |
| 精密ドライバー +0番 | エンジニア +精密ドライバーセット 6本組 DM-20 | https://www.amazon.co.jp/dp/B06XXXVPRY | 807円 |
| テスター | OHM(オーム電機) デジタルマルチテスター TDB-401 (04-1891) | https://www.amazon.co.jp/dp/B001TVKWWU | 2,543円  |
| ハンダ | goot 精密プリント基板用はんだ SD-62 | https://www.amazon.co.jp/dp/B0029LGAMA | 255円 |
| エキポシ接着剤 2液混合タイプ | セメダイン 5分硬化型エポキシ系接着剤 ハイスーパー5 P15gセット CA-188 | https://www.amazon.co.jp/dp/B0036WHO0S | 566円 |
| マスキングテープ | 3M スコッチ 塗装用マスキングテープ 18mm×18m M40J-18 | https://www.amazon.co.jp/dp/B005JWNJZM | 95円 |
| 紙やすり | KAKURI 紙ヤスリMIXセット 12枚入 | https://www.amazon.co.jp/dp/B01ARIEU0A | 436円 |
| 計 | | | 17,362円 |

### 梅コース（価格優先）

| 道具、消耗品 | 製品例 | 調達先の例 | 参考価格 |
| --- | --- | --- | --- |
| はんだこて、交換用こて先、はんだこて台、ハンダ吸取器 | Beneges 温度調整 はんだごて セット | https://www.amazon.co.jp/dp/B077P4GMZW | 2,289円  |
| ニッパー | エンジニア マイクロニッパー NS-04  | https://www.amazon.co.jp/dp/B000TGJSWG | 1,414円  |
| 精密ドライバー +0番 | 精密ドライバーセット | ダイソー | 110円 |
| テスター | Crenova デジタルマルチメーター | https://www.amazon.co.jp/dp/B00KXX2OYY | 1,699円  |
| ハンダ | 電子工作用ハンダ（ヤニ入） | ダイソー | 110円 |
| エキポシ接着剤 2液混合タイプ | 強力接着剤 エキポシ2液混合タイプ | ダイソー | 110円 |
| マスキングテープ | | ダイソー | 110円 |
| 紙やすり | ホビー工作紙ヤスリ 6枚セット | ダイソー | 110円 |
| 計 | | | 6,052円  |

## 解説

### はんだこて

はんだこてとニッパーは100円ショップのものはおすすめしません。

[WEBはんだ付け講座 はじめに・・](https://noseseiki.com/kisokouza/01.html)より

> 現在、日本では趣味ではんだ付けされる方の大半が、温度調節機能のないハンダゴテを使用されています。こうしたハンダゴテはコテ先温度が450～550℃と高く上がりすぎます。このため、このハンダゴテを使ってはんだ付けしたものは、ほとんどがオーバーヒート状態になってしまいます。

ハンダ付けの経験があまりない、またはかなり前にやったという方は温度調整機能付きのものを用意されることを強くおすすめします。ちゃんとしたものを揃えたいという場合は、よくお勧めされる白光のはんだこてがよいと思います。

### 交換先こて先

はんだこてに最初から付いている円錐形のものは対象と点で当たるので熱が伝わりにくく、加熱不足ではんだを置いてしまうということがあるので、2Cのこて先に付け替え、面で加熱できるようにするとやりやすいです。

### はんだこて台

安全にはんだこてを置くために必要です。

### ハンダ吸取器または吸取線

ハンダ付けを失敗したときにないと困るので用意しておくとよいです。

### ニッパー

基板・ビスケットの切り離し、ダイオードの足・ピンヘッダのカットに使います。

ニッパーも100円ショップのものは以下の理由でおすすめしません。

- 切れ味があまり良くなく、ダイオードの足やピンヘッダが切りにくい
- 刃がツライチではないので、ギリギリに切れない

### テスター

キーが入力できない場合の問題切り分けに必要です。

導通モードがあればよいです。

### 電子工作用ハンダ

有鉛タイプが作業しやすいです。

SU120に使う部品に特段小さいものはないので1mmのものでも十分作業できますが、0.8mmだとはんだが溶けやすいようです。

### エポキシ接着剤 2液混合タイプ

Pro Microのもげ防止加工に使います。

### マスキングテープ

ハンダ付けで基板を裏返す際に部品を固定しておくのに使います。

## 参考になるWebページ

上の調達製品例・解説は個人の私見ですので、もう少し広く情報収集したい場合は以下のリンク先が参考になります。

- [Helix キーボードキットの製作に必要な工具メモ - GitHub](https://gist.github.com/mtei/6957107a676ddfa85bde0ae41f8fa849)
- [自作キーボードを作るために必要なもの - 自作キーボード温泉街の歩き方](https://salicylic-acid3.hatenablog.com/entry/2018/11/24/自作キーボードを作るために必要なもの)
- [自作キーボードの組み立てに使っている工具 | yfuku docs](https://yfuku.com/blog/keyboard/keybord_build_tool/)
- [elephant42 の組み立てかた#工具の準備 · illness072/elephant42](https://github.com/illness072/elephant42/blob/master/docs/build-guide.md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)
- [基礎からわかる！自キ入門講座 第8回「自作キーボードのつくりかた #2」 - YouTube](https://www.youtube.com/watch?v=LOC53FeU-QM)

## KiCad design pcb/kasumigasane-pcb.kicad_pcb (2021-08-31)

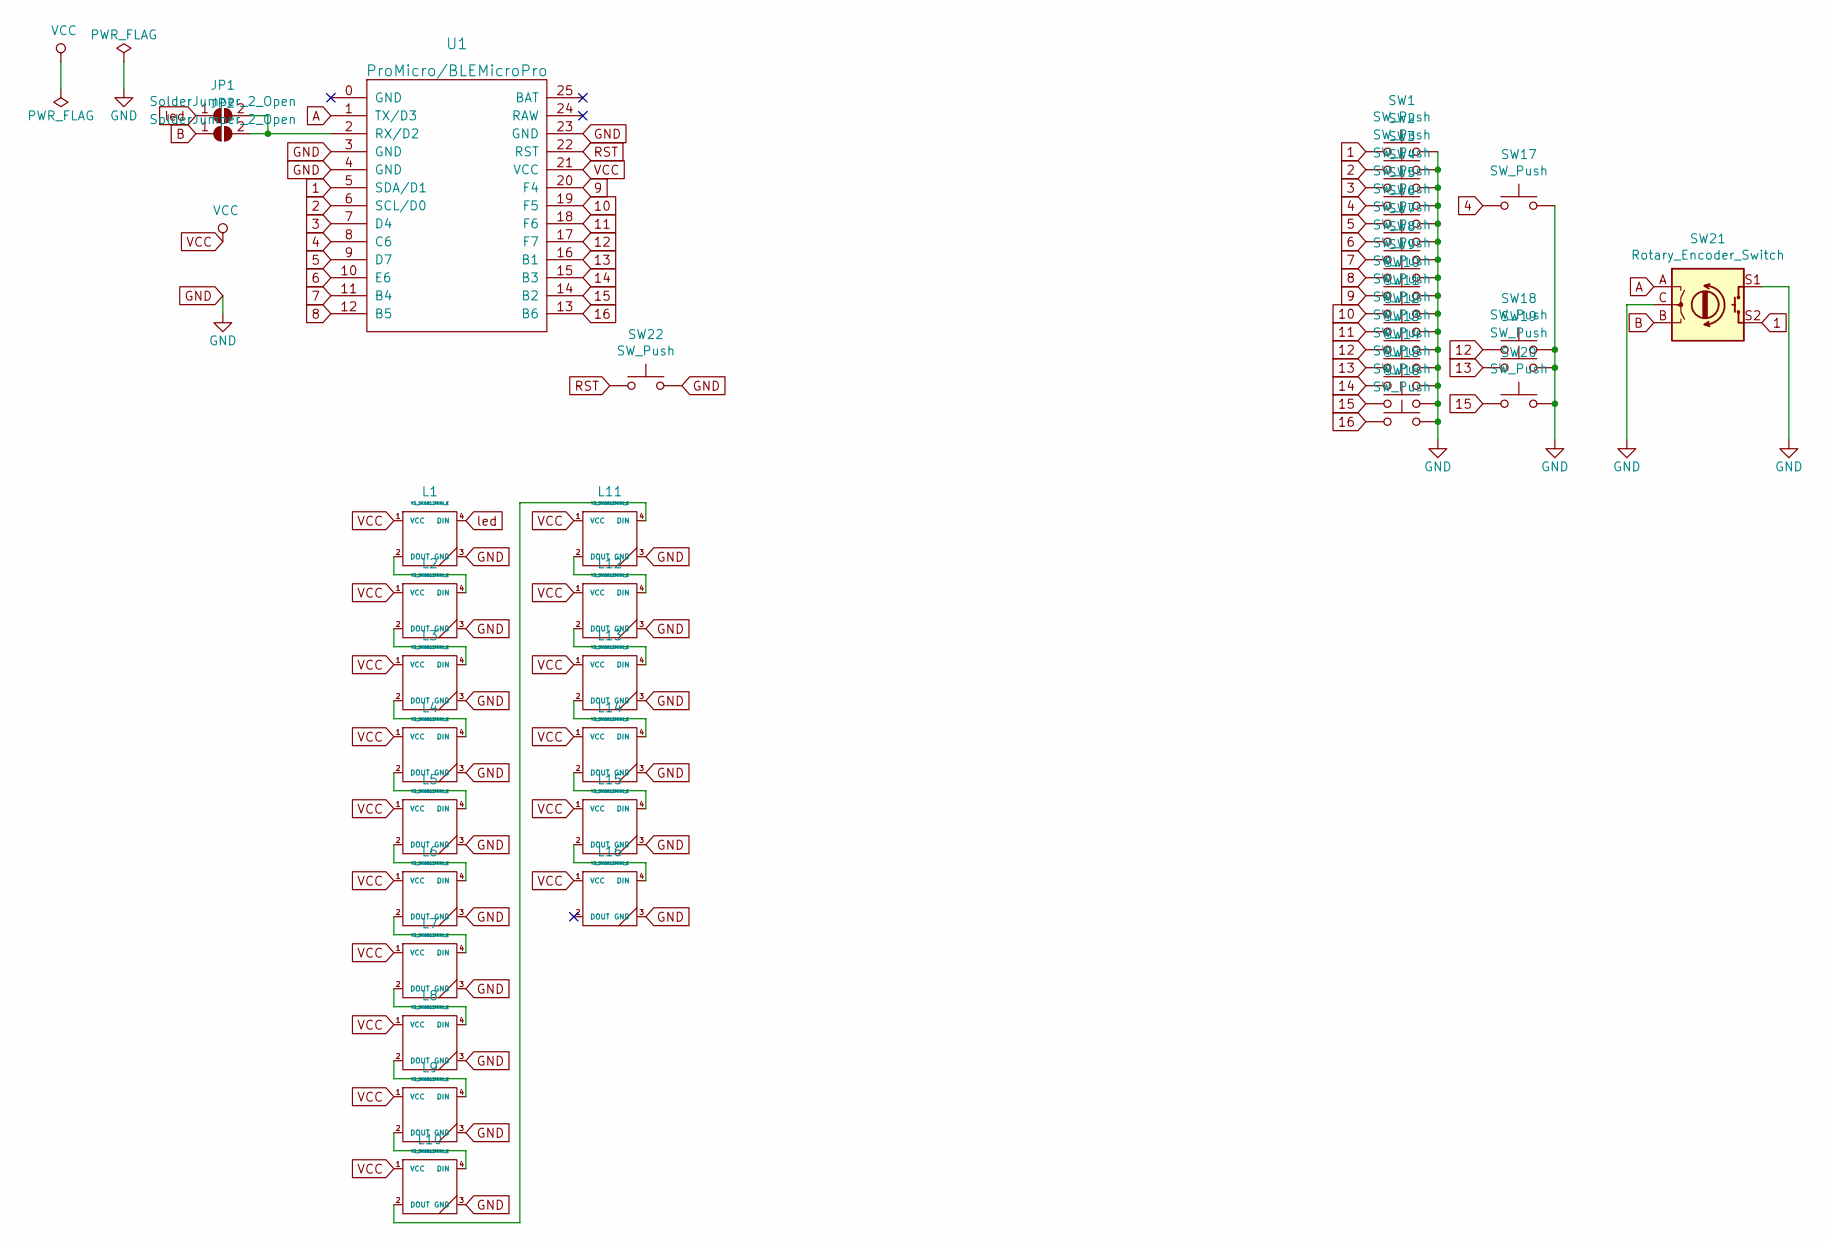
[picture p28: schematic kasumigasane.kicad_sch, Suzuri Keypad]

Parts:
JP1, JP2: SolderJumper_2_Open; SolderJumper-2_P1.3mm_Open_Pad1.0x1.0mm
L1, L2, L3, L4, L5, L6, L7, L8, L9, L10, L11, L12, L13, L14, L15, L16: YS_SK6812MINI_E; YS-SK6812MINI-E
SW1, SW2, SW3, SW4, SW5, SW6, SW7, SW8, SW9, SW10, SW11, SW12, SW13, SW14, SW15, SW16, SW17, SW18, SW19, SW20: SW_Push; CherryMX
SW21: Rotary_Encoder_Switch; RotaryEncoder_Alps_EC11E-Switch_Vertical_H20mm_rev2
SW22: SW_Push; ResetSW
U1: ProMicro/BLEMicroPro; ArduinoProMicro_ConThrough

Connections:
1: SW1.1, SW21.S2, U1.5 (SDA/D1)
2: SW2.1, U1.6 (SCL/D0)
3: SW3.1, U1.7 (D4)
4: SW4.1, SW17.1, U1.8 (C6)
5: SW5.1, U1.9 (D7)
6: SW6.1, U1.10 (E6)
7: SW7.1, U1.11 (B4)
8: SW8.1, U1.12 (B5)
9: SW9.1, U1.20 (F4)
10: SW10.1, U1.19 (F5)
11: SW11.1, U1.18 (F6)
12: SW12.1, SW18.1, U1.17 (F7)
13: SW13.1, SW19.1, U1.16 (B1)
14: SW14.1, U1.15 (B3)
15: SW15.1, SW20.1, U1.14 (B2)
16: SW16.1, U1.13 (B6)
A: SW21.A, U1.1 (TX/D3)
B: JP2.1 (A), SW21.B
GND: L1.3 (GND), L2.3 (GND), L3.3 (GND), L4.3 (GND), L5.3 (GND), L6.3 (GND), L7.3 (GND), L8.3 (GND), L9.3 (GND), L10.3 (GND), L11.3 (GND), L12.3 (GND), L13.3 (GND), L14.3 (GND), L15.3 (GND), L16.3 (GND), SW1.2, SW2.2, SW3.2, SW4.2, SW5.2, SW6.2, SW7.2, SW8.2, SW9.2, SW10.2, SW11.2, SW12.2, SW13.2, SW14.2, SW15.2, SW16.2, SW17.2, SW18.2, SW19.2, SW20.2, SW21.C, SW21.S1, SW22.2, U1.3 (GND), U1.4 (GND), U1.23 (GND)
unnamed: JP1.2 (B), JP2.2 (B), U1.2 (RX/D2)
unnamed: L1.2 (DOUT), L2.4 (DIN)
unnamed: L2.2 (DOUT), L3.4 (DIN)
unnamed: L3.2 (DOUT), L4.4 (DIN)
unnamed: L4.2 (DOUT), L5.4 (DIN)
unnamed: L5.2 (DOUT), L6.4 (DIN)
unnamed: L6.2 (DOUT), L7.4 (DIN)
unnamed: L7.2 (DOUT), L8.4 (DIN)
unnamed: L8.2 (DOUT), L9.4 (DIN)
unnamed: L10.2 (DOUT), L11.4 (DIN)
unnamed: L9.2 (DOUT), L10.4 (DIN)
unnamed: L11.2 (DOUT), L12.4 (DIN)
unnamed: L12.2 (DOUT), L13.4 (DIN)
unnamed: L13.2 (DOUT), L14.4 (DIN)
unnamed: L14.2 (DOUT), L15.4 (DIN)
unnamed: L15.2 (DOUT), L16.4 (DIN)
RST: SW22.1, U1.22 (RST)
VCC: L1.1 (VCC), L2.1 (VCC), L3.1 (VCC), L4.1 (VCC), L5.1 (VCC), L6.1 (VCC), L7.1 (VCC), L8.1 (VCC), L9.1 (VCC), L10.1 (VCC), L11.1 (VCC), L12.1 (VCC), L13.1 (VCC), L14.1 (VCC), L15.1 (VCC), L16.1 (VCC), U1.21 (VCC)
led: JP1.1 (A), L1.4 (DIN)

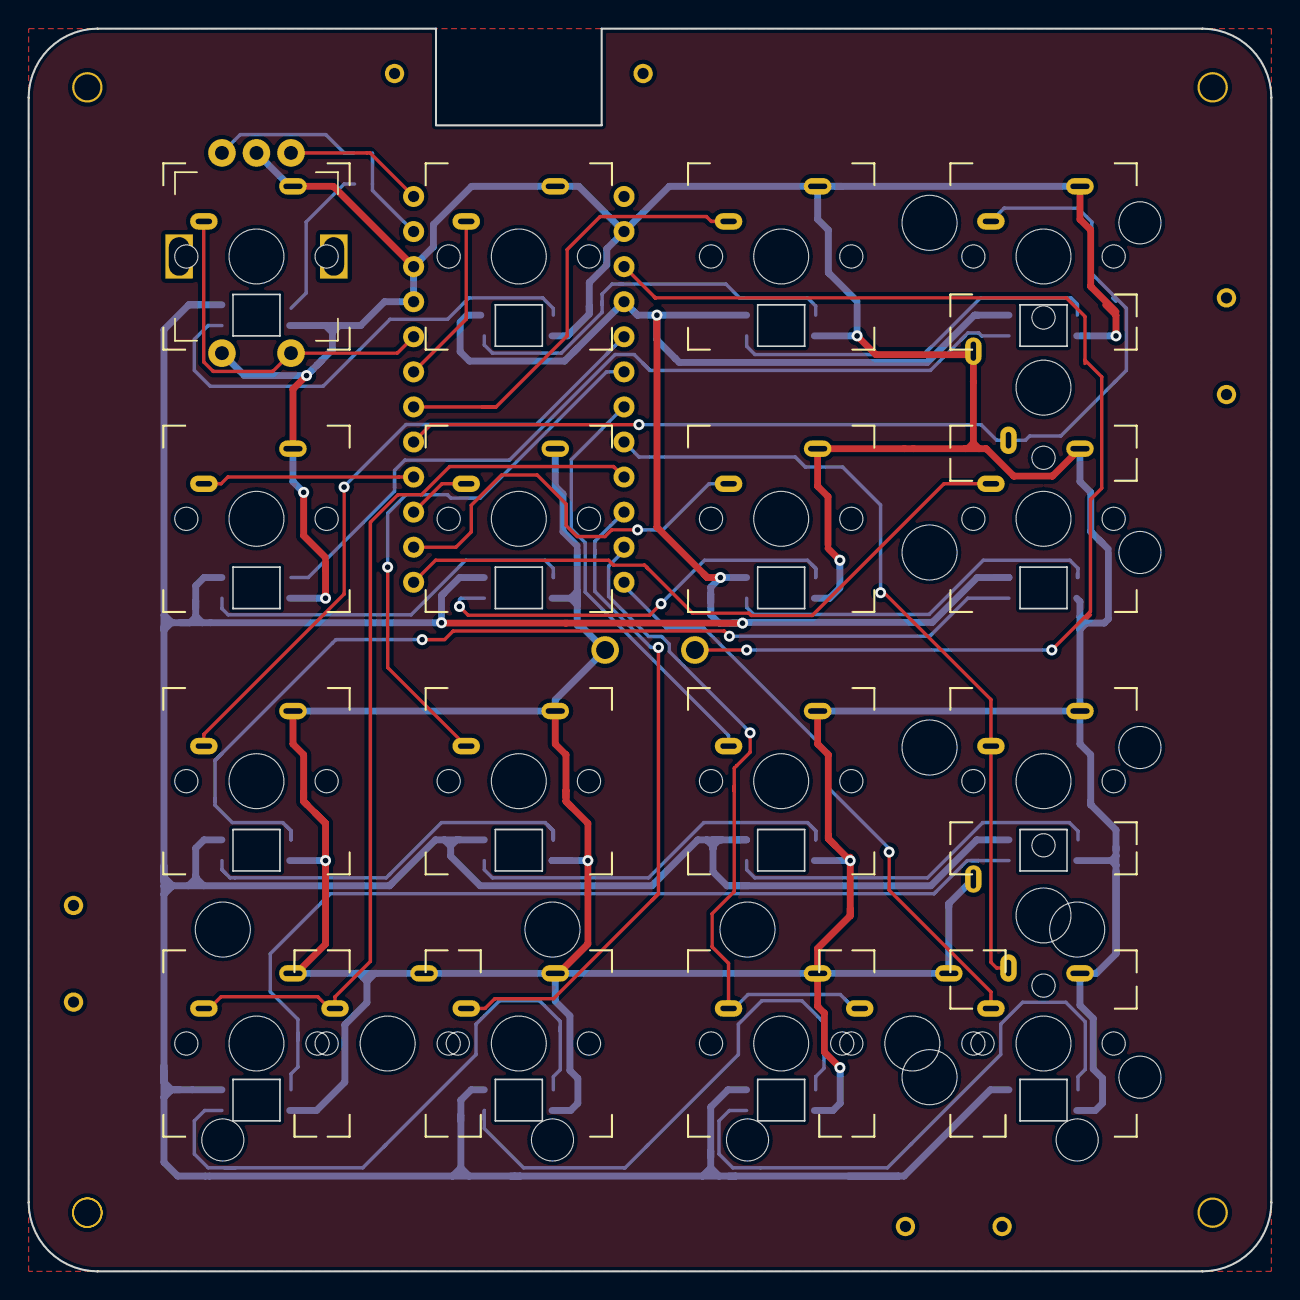
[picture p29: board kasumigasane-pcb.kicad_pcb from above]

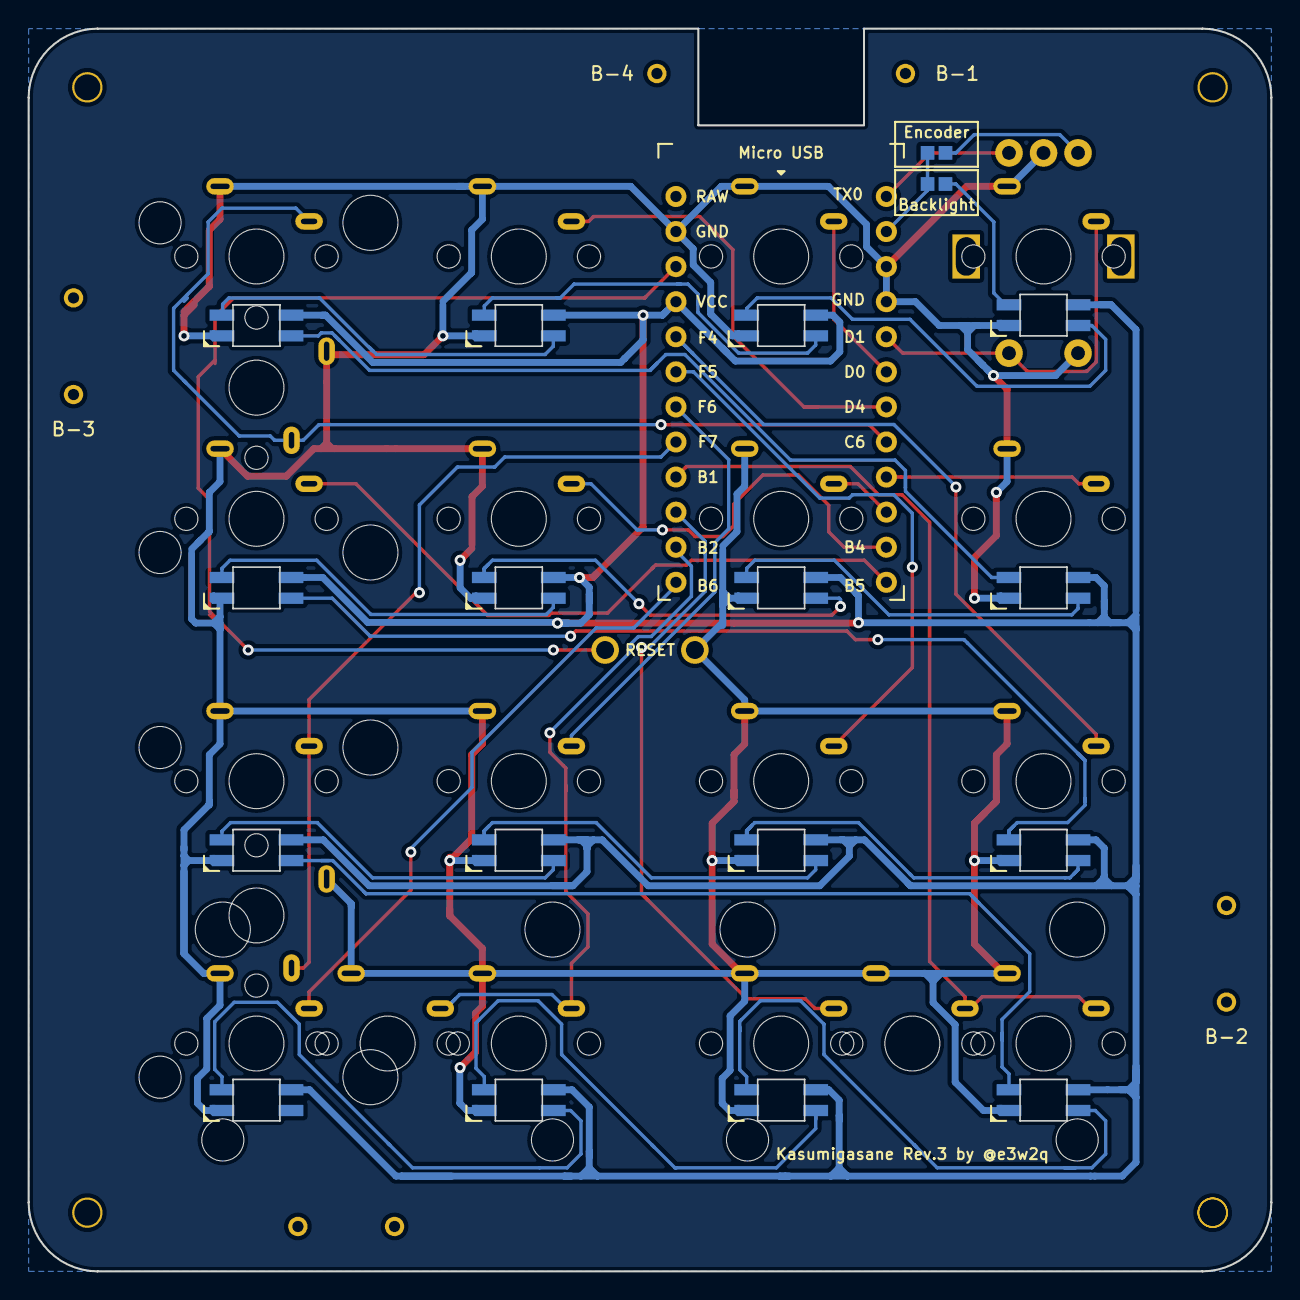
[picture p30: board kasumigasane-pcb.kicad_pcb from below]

Board: 2 copper layers, 90.0 x 90.0 mm, 41 parts (4 on the bottom side), 38 nets.

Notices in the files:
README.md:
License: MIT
